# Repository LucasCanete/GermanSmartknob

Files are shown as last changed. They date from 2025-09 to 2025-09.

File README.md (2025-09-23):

# German Smartknob
An ESP32-S3 based knob to control smart devices at home. Based on Scott Bez's Smartknob: https://github.com/scottbez1/smartknob?tab=readme-ov-file. Adapted for the standard german wall socket.

## Table of Contents
1. [About the Project](#about-the-project)
2. [Features](#features)
3. [Components](#components)
4. [Getting Started](#getting-started)
5. [Project Status](#project-status)

## About the project
This project mechatronic project has three main parts. The first part consisted of the development of a PCB that could fit in the standard german wall socket and would control sensors, touch display and a BLDC Motor. The second part consisted on 3d printed pieces to sustain the PCB on its place, allow BLDC rotation while keeping the touch display on its place. Finally the third part was the software, which tested that all sensors and actuators worked accordingly. The final product can be seen below. 
<p align="center">
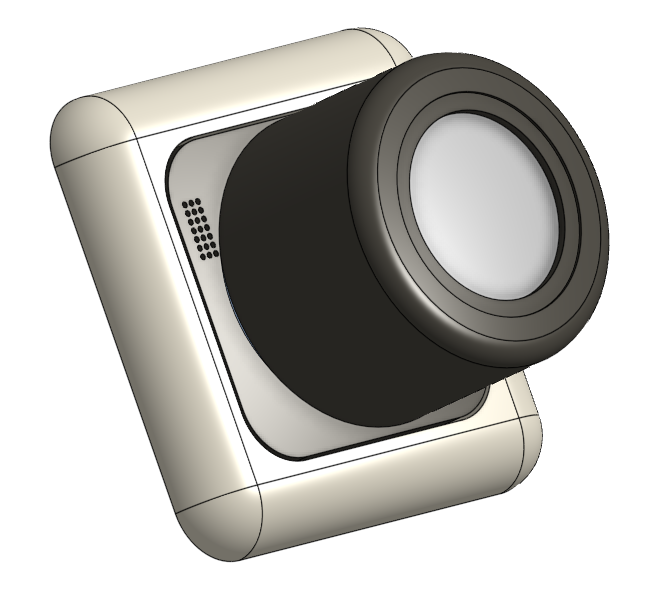
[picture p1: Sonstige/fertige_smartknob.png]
smartknob
   <br>
   <em>German Smartknob</em>
</p>

## Features
- ESP32-S3 based PCB
- Input Voltage of up to 24V
- Haptic Feedback with a BLDC-Motor (Coming soon)
- Touch Display
- Brightness and Temperature Sensor
- Audio speaker connectors

## Components
A summarized description of this products three main parts.
### PCB
The PCB was designed to fit into the standard german wall socket. It has two sides. 

On the front side there is a ring of RGB Leds for user feedback and at its center a magnetic encoder. The magnetic encoder is key to detect the rotation's direction of the BLDC Motor, that in this project is used as an input device, similar to a rotary encoder. The reason why a BLDC Motor was chosen and not a regular rotary encoder, is because with the first, through proper driver, it is possible to program the motor's torque and adjust it according to the user's use. Besides of this, at the sides of the Front-PCB there are sensors to detect the temperature, the room's brightness and also output audio via a speaker.

<p align="center">
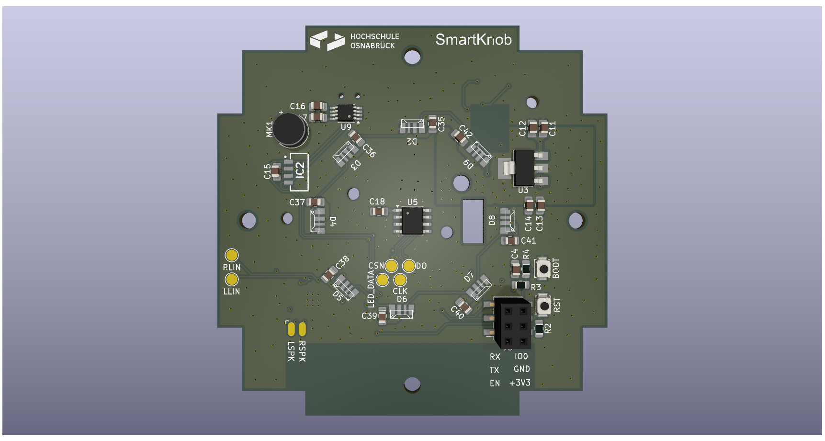
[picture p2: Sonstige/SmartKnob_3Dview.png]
Front side
   <br>
   <em>Figure 1: Front side PCB</em>
</p>

On the back side there are connectors available to supply the PCB with 24V, 3.3v and extra outputs with I2C and CAN lines. The Display connector pads, the ESP32-S3, and the audio and bldc driver are also found on the back side of the PCB.

<p align="center">
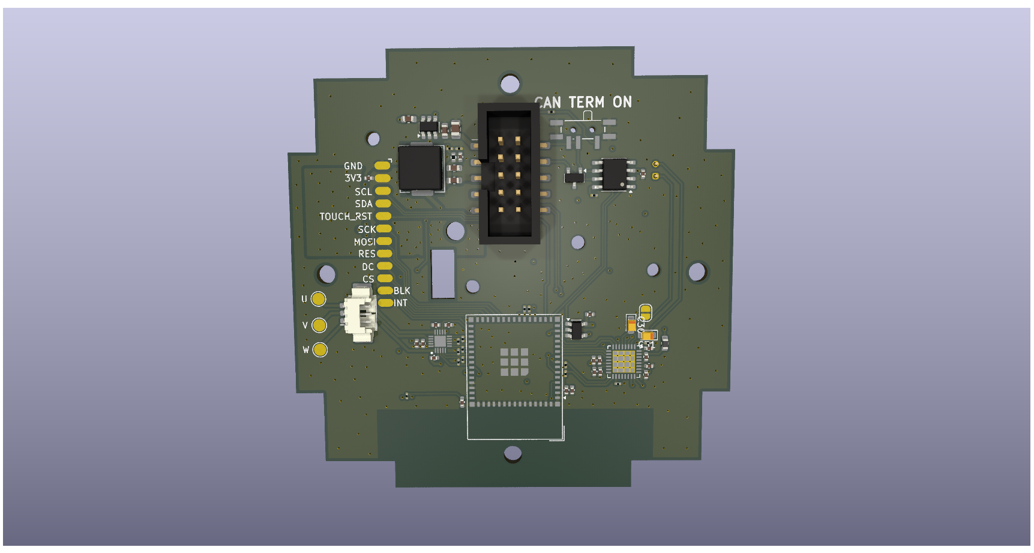
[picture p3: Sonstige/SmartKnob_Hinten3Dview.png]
Back side
   <br>
   <em>Figure 2: Backside PCB</em>
</p>

### 3D printed Parts
Using the OnShape CAD tool several 3D pieces were designed, that later were 3d printed. The pieces include a holder for the BLDC Motor to keep it in the middle; a holder for the display, a knob and a case to hide the electronic. Below is an exploded view of the internal pieces of the smartknob.

<p align="center">
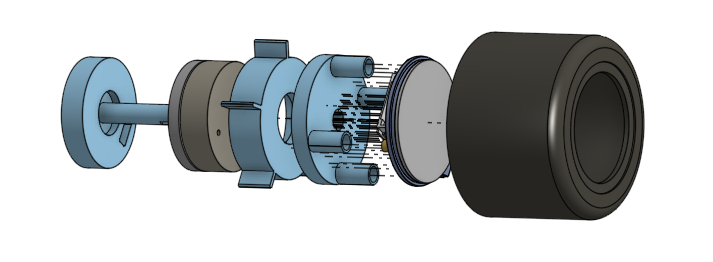
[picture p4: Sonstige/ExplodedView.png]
Exploded View
   <br>
   <em>Figure 3: Internal Pieces </em>
</p>

### Software
The software was built using the arduino libraries, for simplicities sake. The main goal of the software program was to demonstrate the correct functioning of the main features of the smartknob. Because of this, a small Manu was programmed in which 4 main features can be selected as options. With a tap on the touch display the option can be selected and the functioning of the feature can be demonstrated.

The four menu options and what each of them does is represented with the diagram below:

<p align="center">
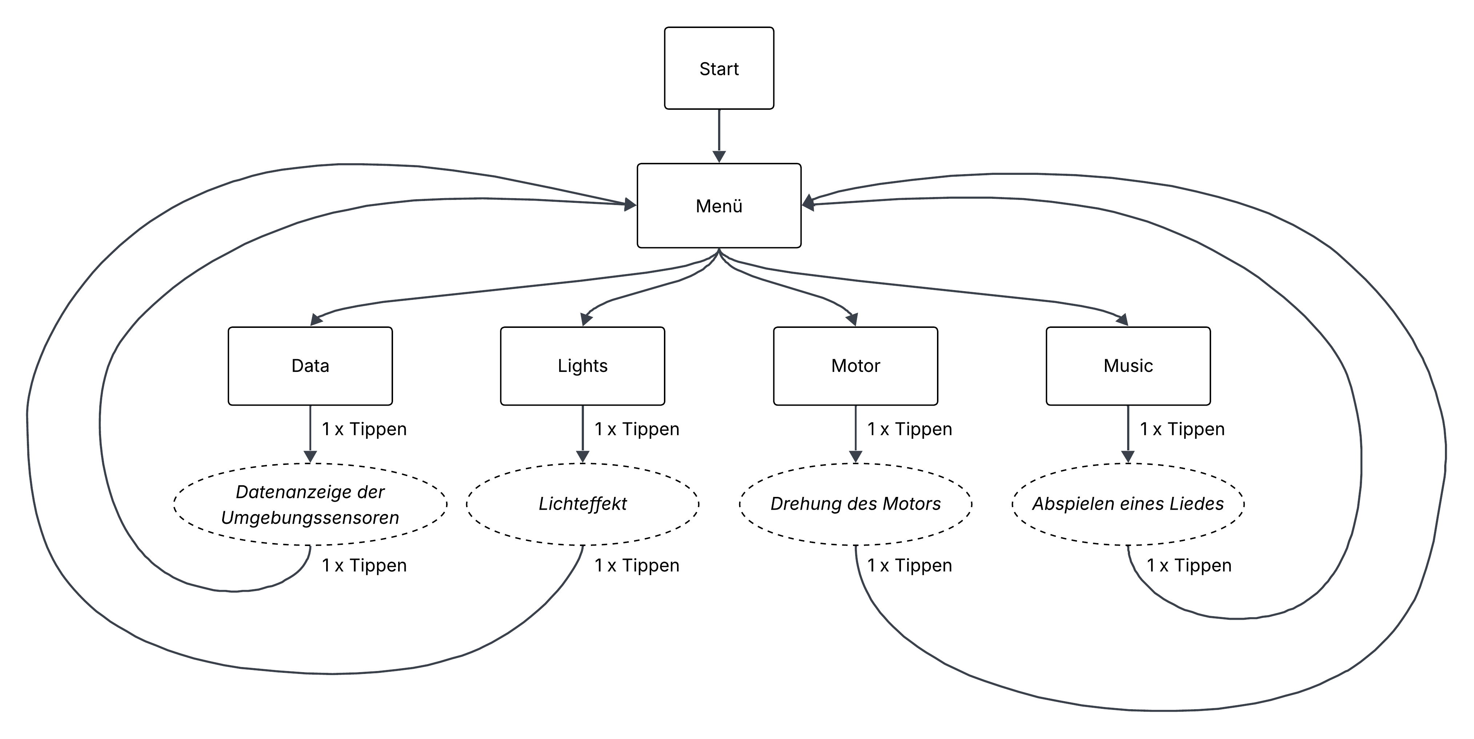
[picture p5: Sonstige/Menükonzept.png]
Software Diagram
   <br>
   <em>Figure 4: Software Diagram </em>
</p>

## Getting Started

### Download this repo
```
git clone https://github.com/LucasCanete/GermanSmartknob.git
```
### Build and upload 

### How To Use

<p align="center">
   Design 
 
   kitchenalarm
</p>

## Project Status
This project is still under development. Eventhough the first version was successful, improvements are still coming to the software side. Some of them are:
- [ ] Full implementation of haptic feedback
- [ ] Connection to smart devices over MQTT, home assistant, etc

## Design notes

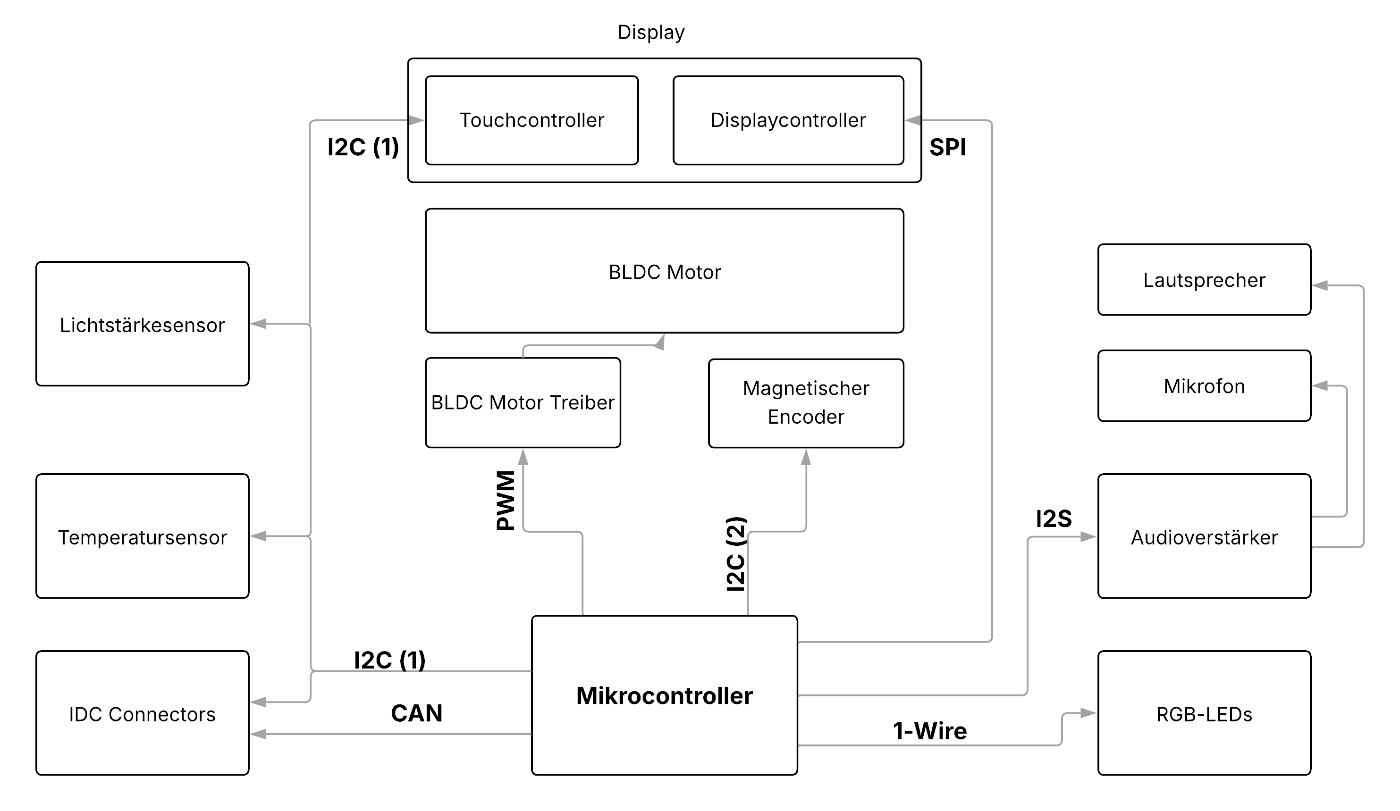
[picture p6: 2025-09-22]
Sonstige/HardwareArchitektur.png

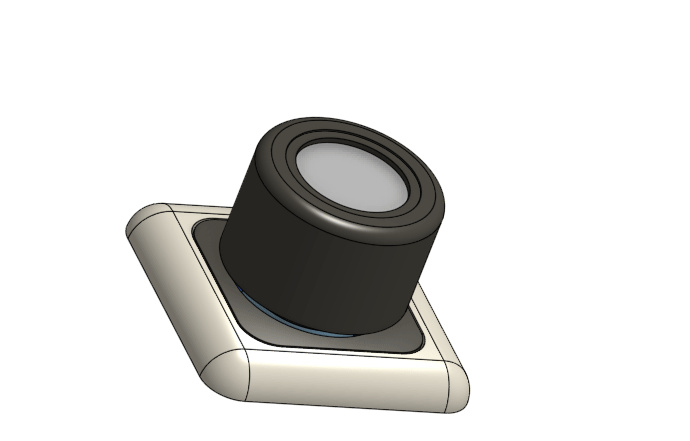
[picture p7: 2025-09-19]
Sonstige/drehung_1.gif

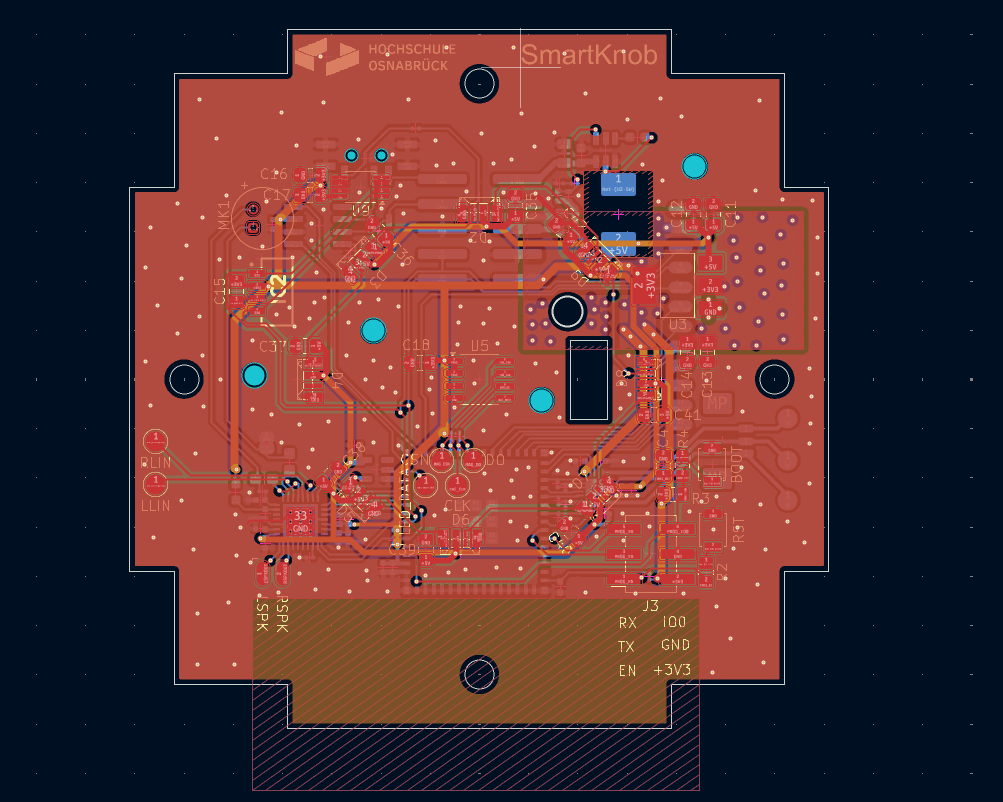
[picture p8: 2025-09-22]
Sonstige/2.ElektronischeArchitektur/Screenshot_Platine.png

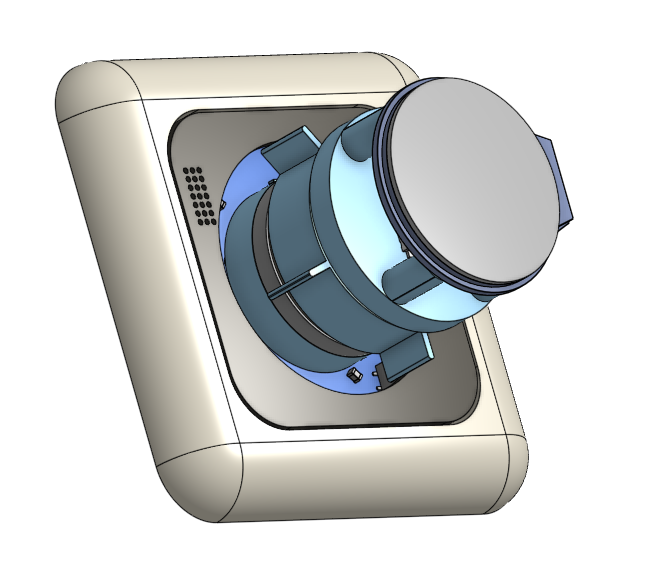
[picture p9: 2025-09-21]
Sonstige/Case.png

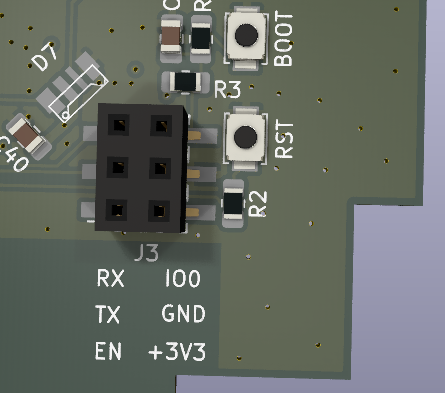
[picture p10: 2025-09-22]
Sonstige/2.ElektronischeArchitektur/screenshot_proganschluss.png

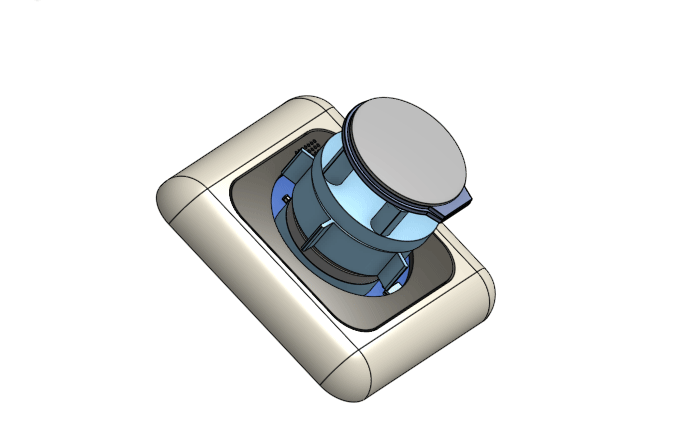
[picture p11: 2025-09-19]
Sonstige/drehung_2.gif

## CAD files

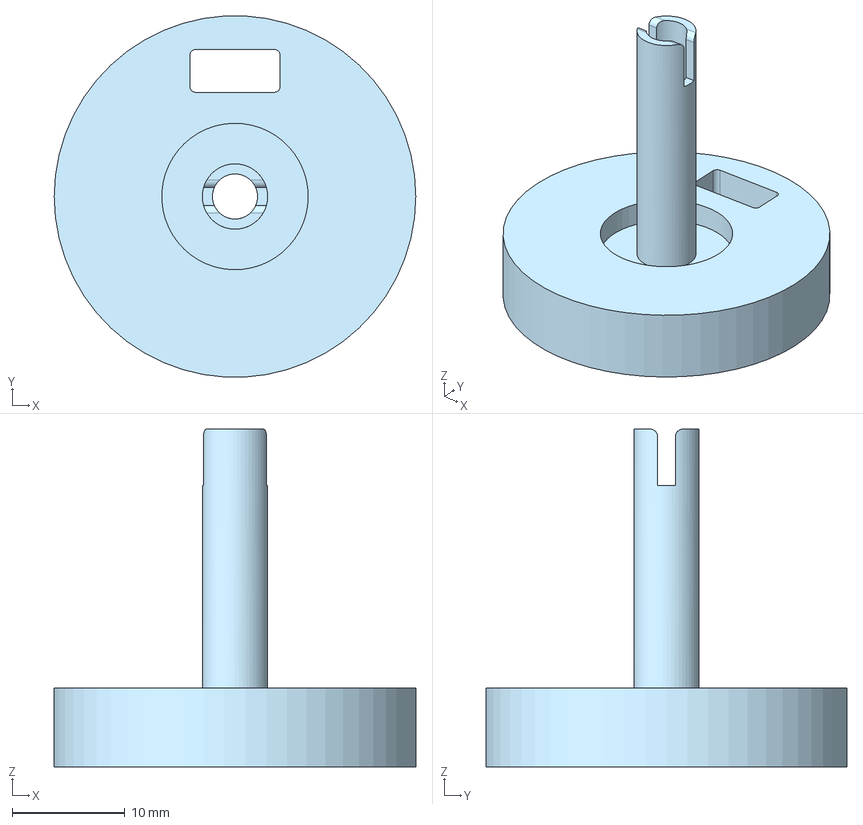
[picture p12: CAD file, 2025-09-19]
3DModelle/STEP/halterung.step
32.1 x 32.0 x 30.0 mm

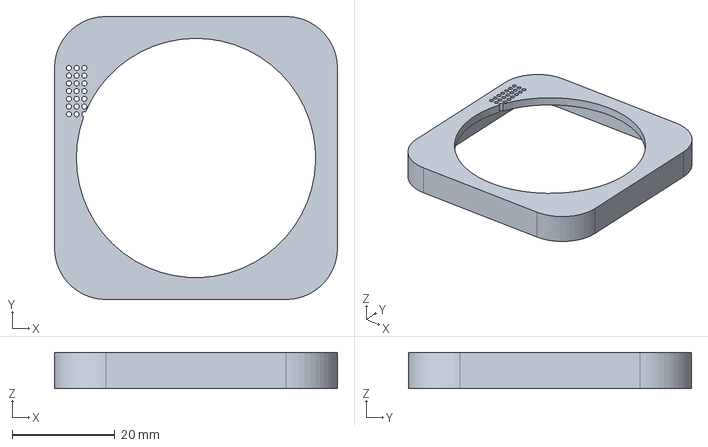
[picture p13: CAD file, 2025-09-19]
3DModelle/STEP/blende.step
55.0 x 55.0 x 7.00 mm

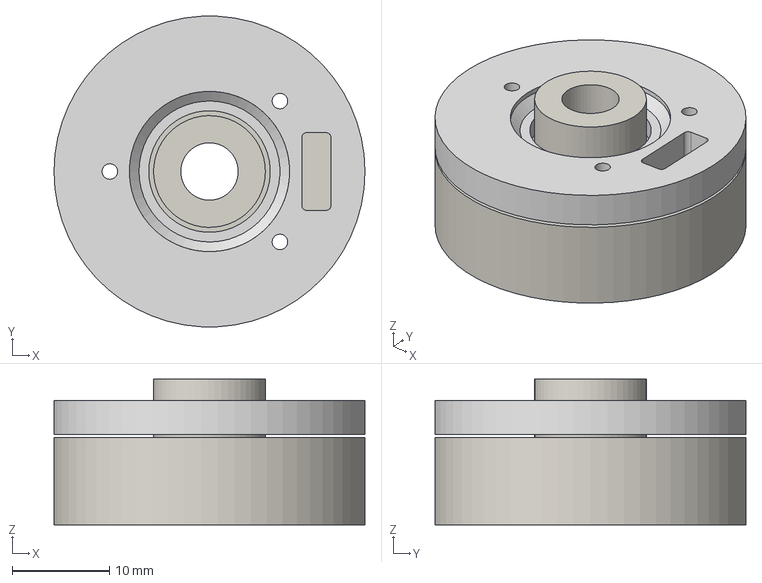
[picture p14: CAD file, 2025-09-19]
3DModelle/STEP/motor.step
32.0 x 32.0 x 15.0 mm

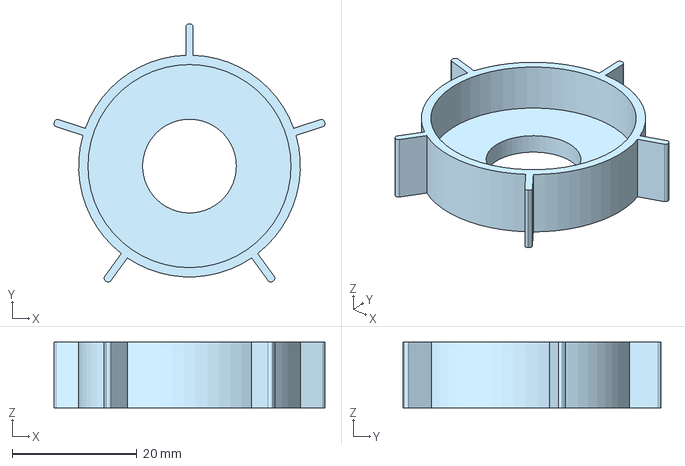
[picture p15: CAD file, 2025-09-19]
3DModelle/STEP/drehaufsatz.step
43.4 x 41.3 x 10.5 mm

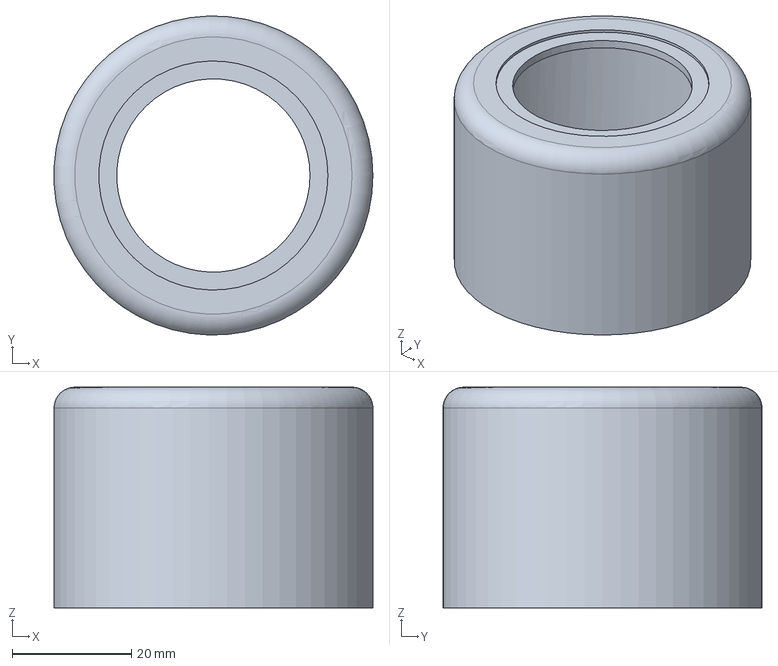
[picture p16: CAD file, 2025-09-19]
3DModelle/STEP/drehadapter.step
53.5 x 53.5 x 37.0 mm

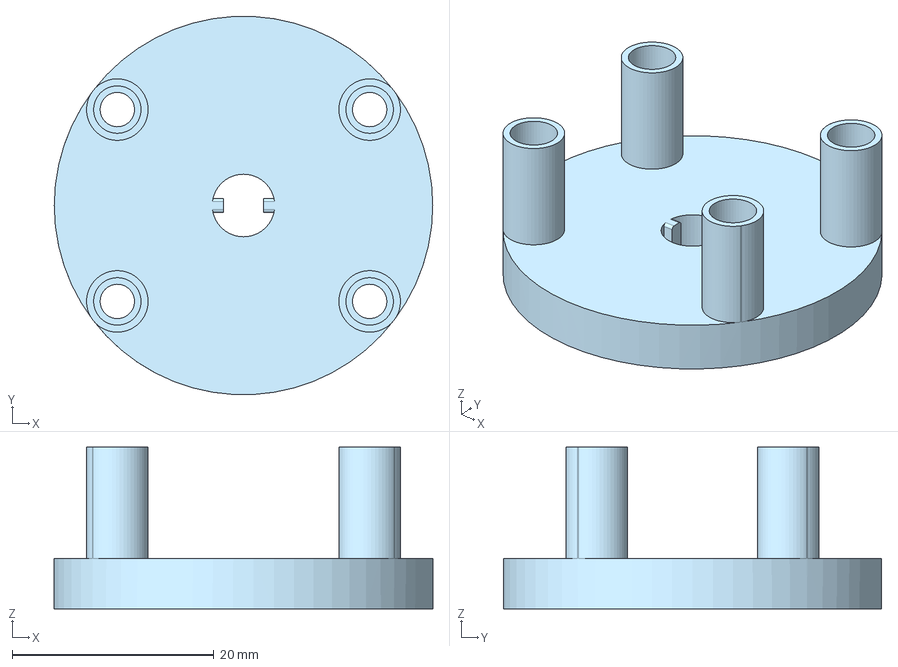
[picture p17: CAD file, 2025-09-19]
3DModelle/STEP/displayhalter.step
37.5 x 37.4 x 16.0 mm

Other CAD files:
3DModelle/STL/blende.stl
3DModelle/STL/displayhalter.stl
3DModelle/STL/drehadapter.stl
3DModelle/STL/drehaufsatz.stl
3DModelle/STL/halterung.stl

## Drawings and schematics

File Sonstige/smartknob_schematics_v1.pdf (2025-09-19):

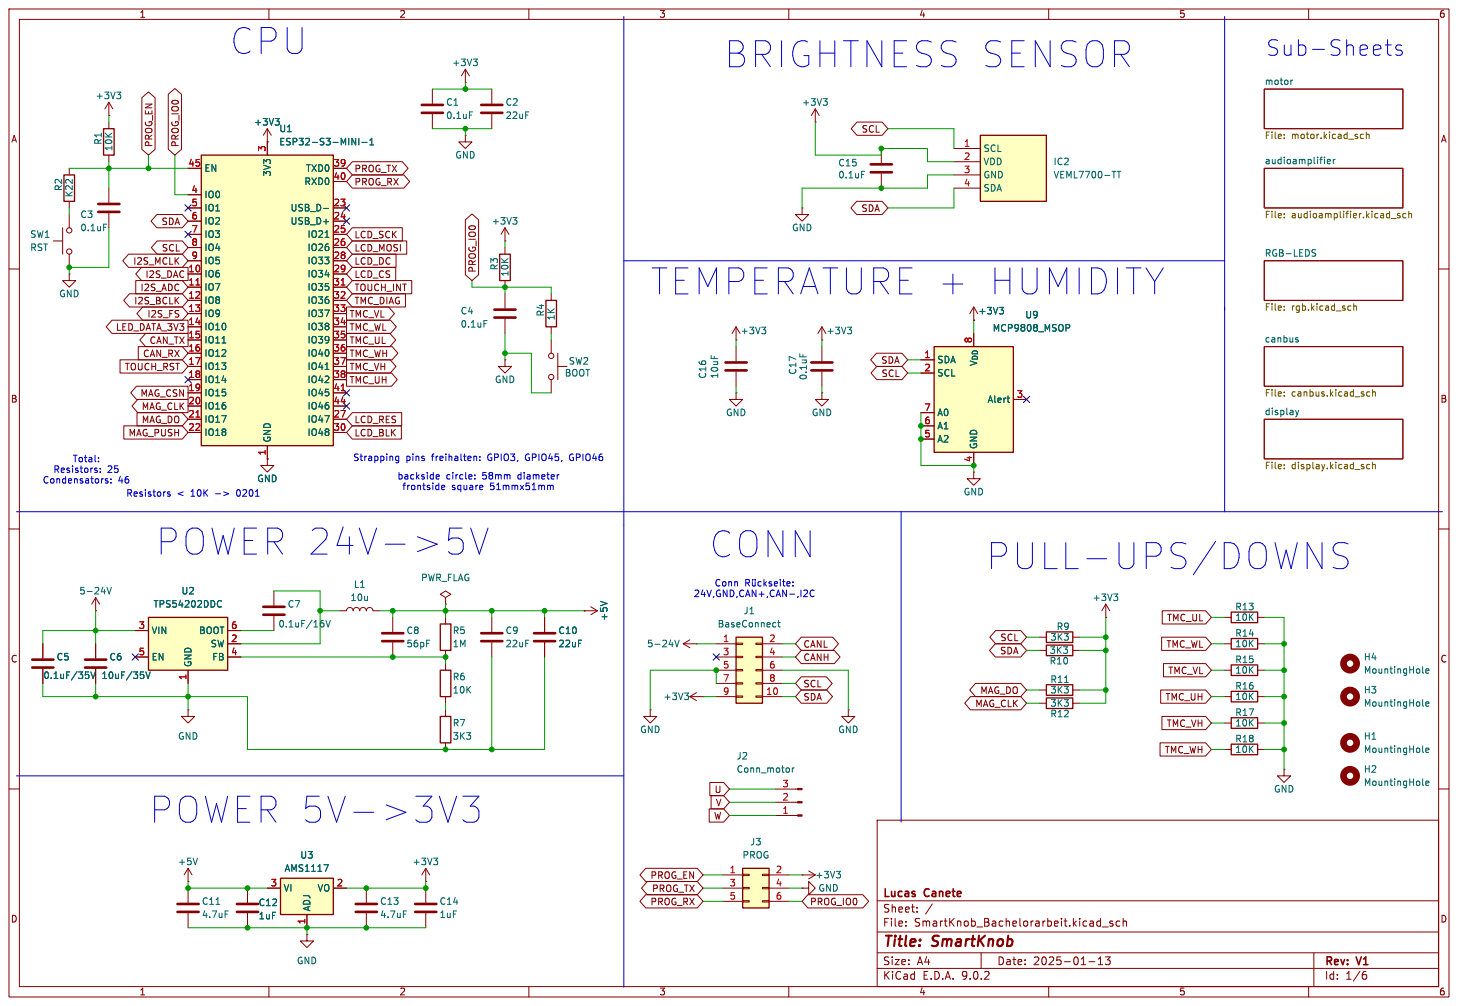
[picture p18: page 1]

File: rgb.kicad_sch motor File: motor.kicad_sch

canbus File: canbus.kicad_sch RGB-LEDS

CONN
PULL-UPS/DOWNS Conn þÿRückseite: 24V,GND,CAN+,CAN-,I2C

File: SmartKnob_Bachelorarbeit.kicad_sch Sheet: / Lucas Canete

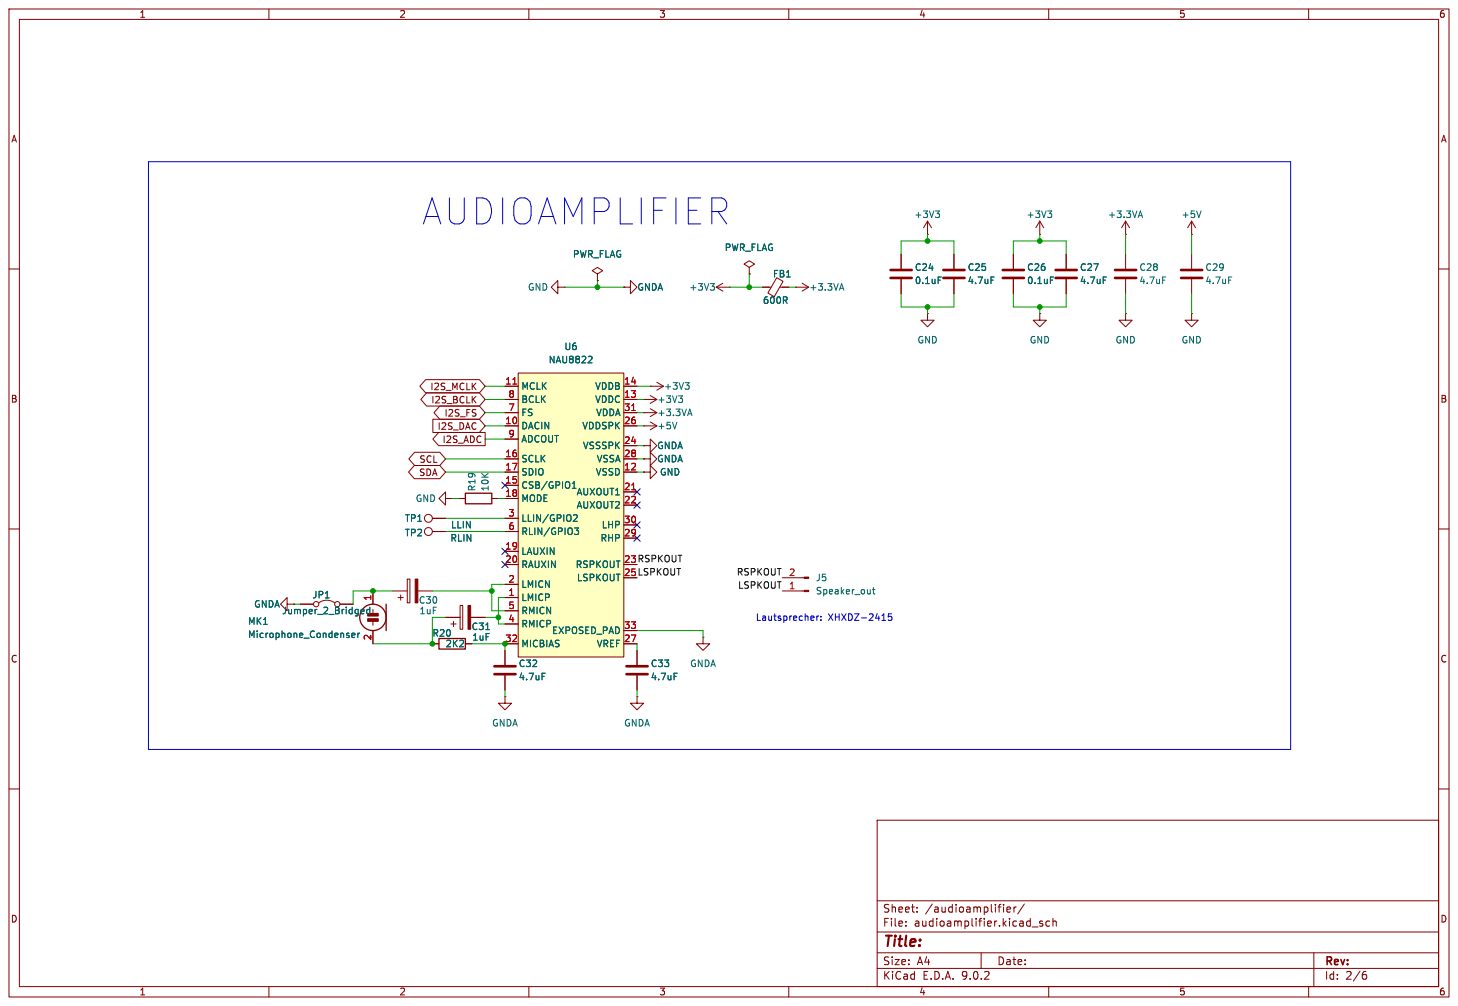
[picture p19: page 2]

Id: 2/6 Title: File: audioamplifier.kicad_sch Sheet: /audioamplifier/

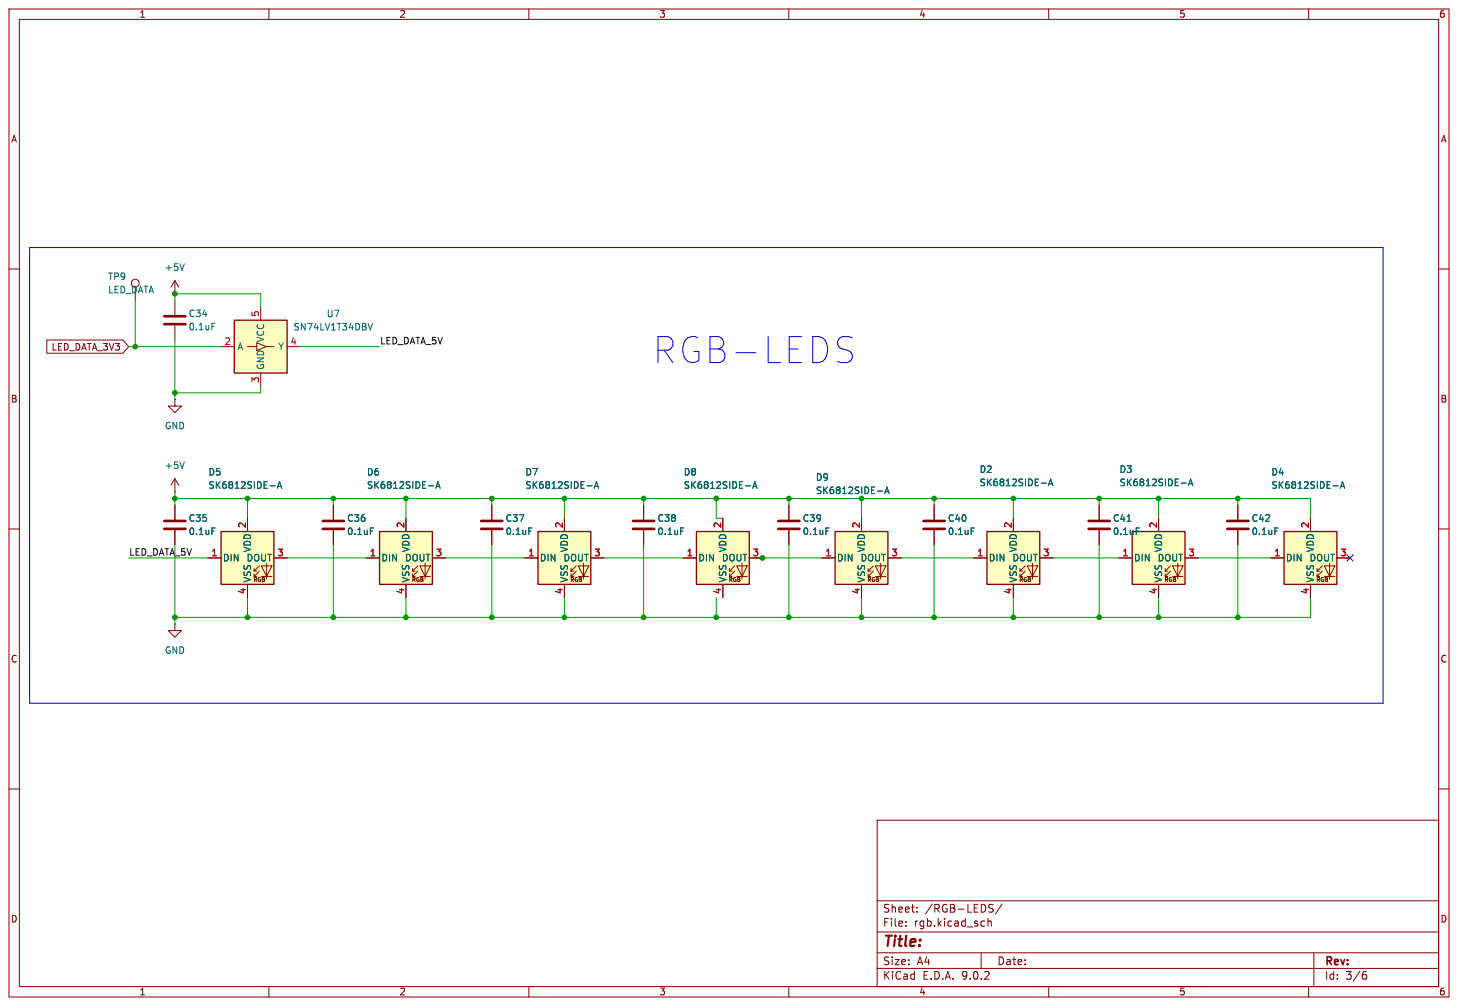
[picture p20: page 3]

Id: 3/6 Title: File: rgb.kicad_sch Sheet: /RGB-LEDS/ C38

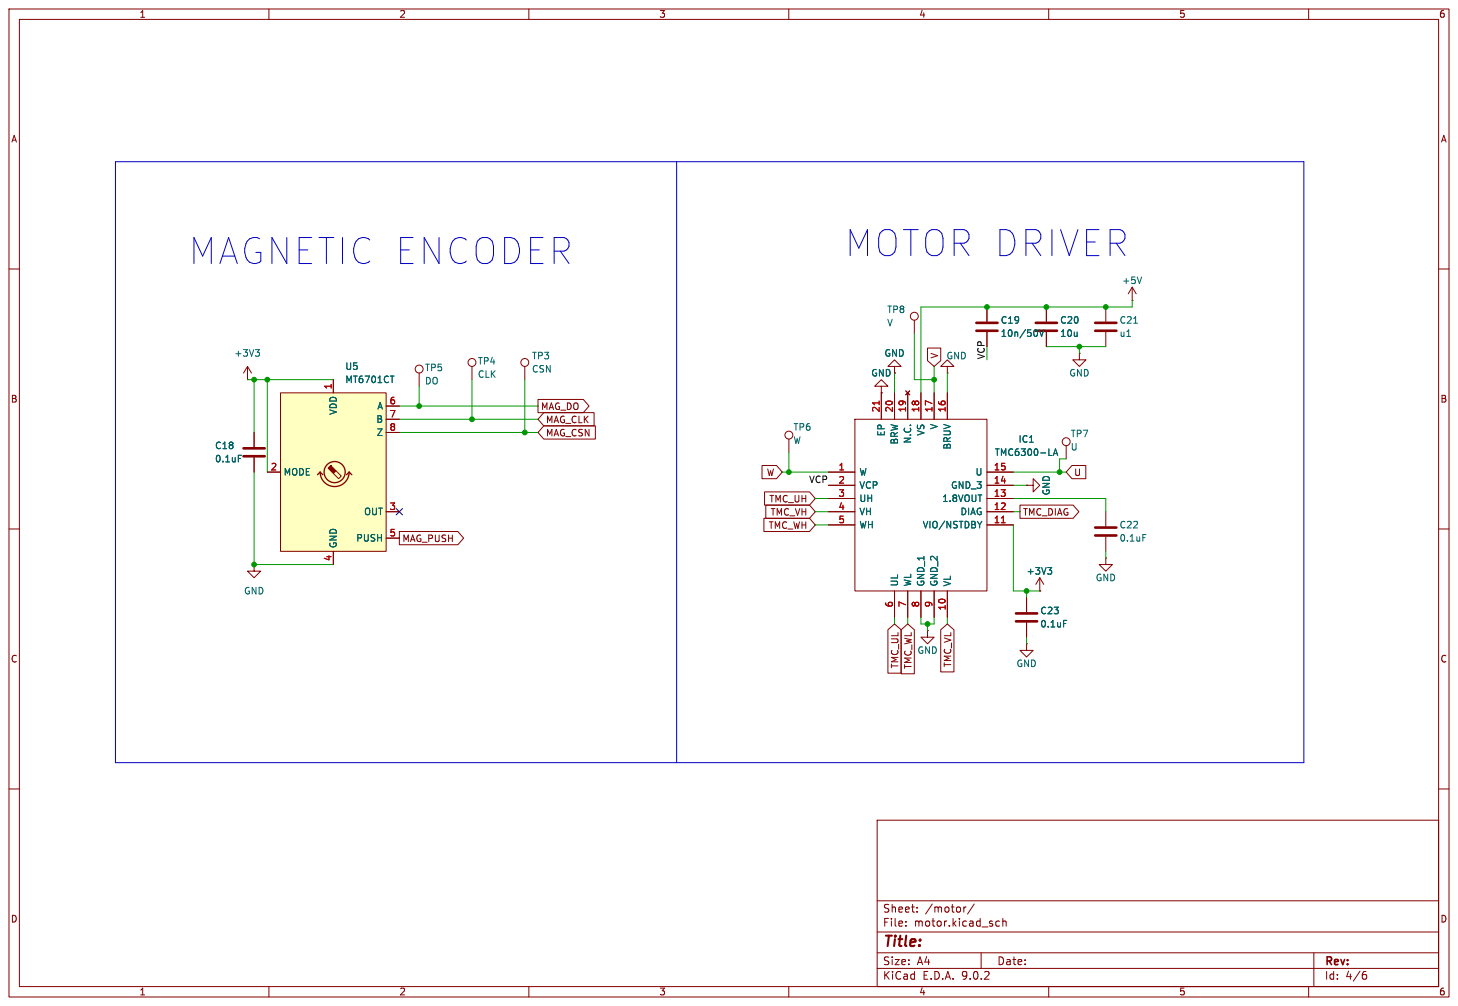
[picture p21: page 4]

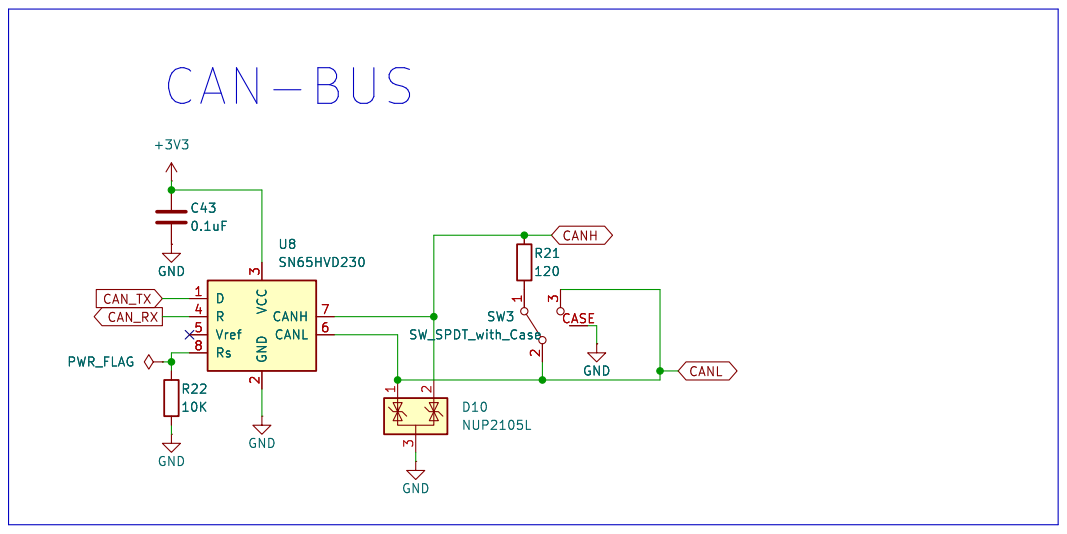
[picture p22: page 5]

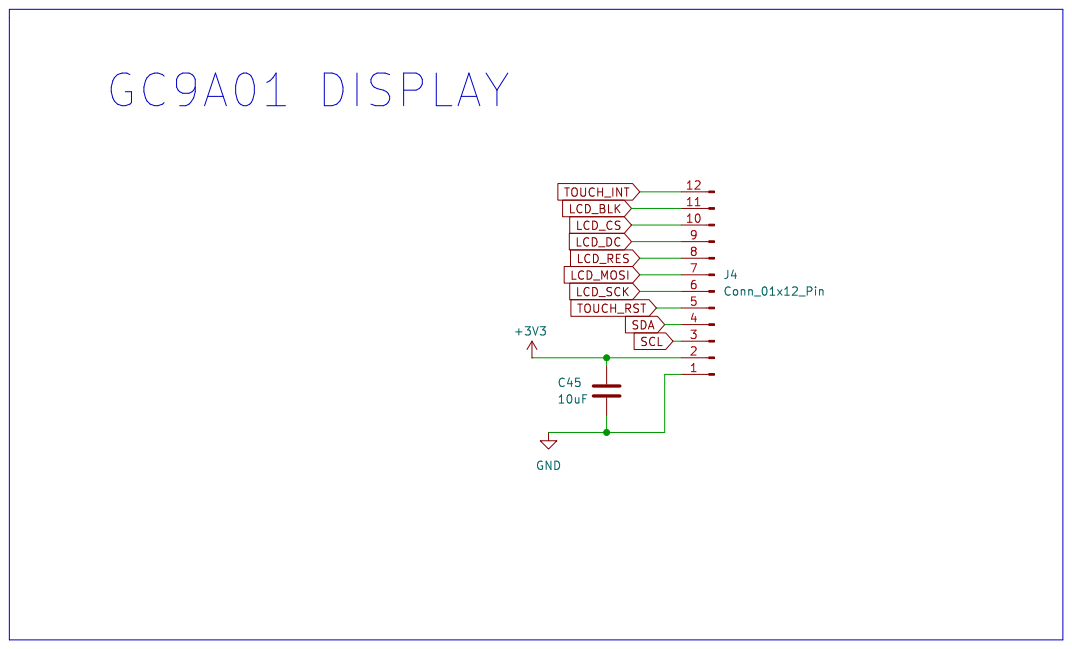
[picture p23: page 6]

Id: 6/6 Title: File: display.kicad_sch Sheet: /display/ GND

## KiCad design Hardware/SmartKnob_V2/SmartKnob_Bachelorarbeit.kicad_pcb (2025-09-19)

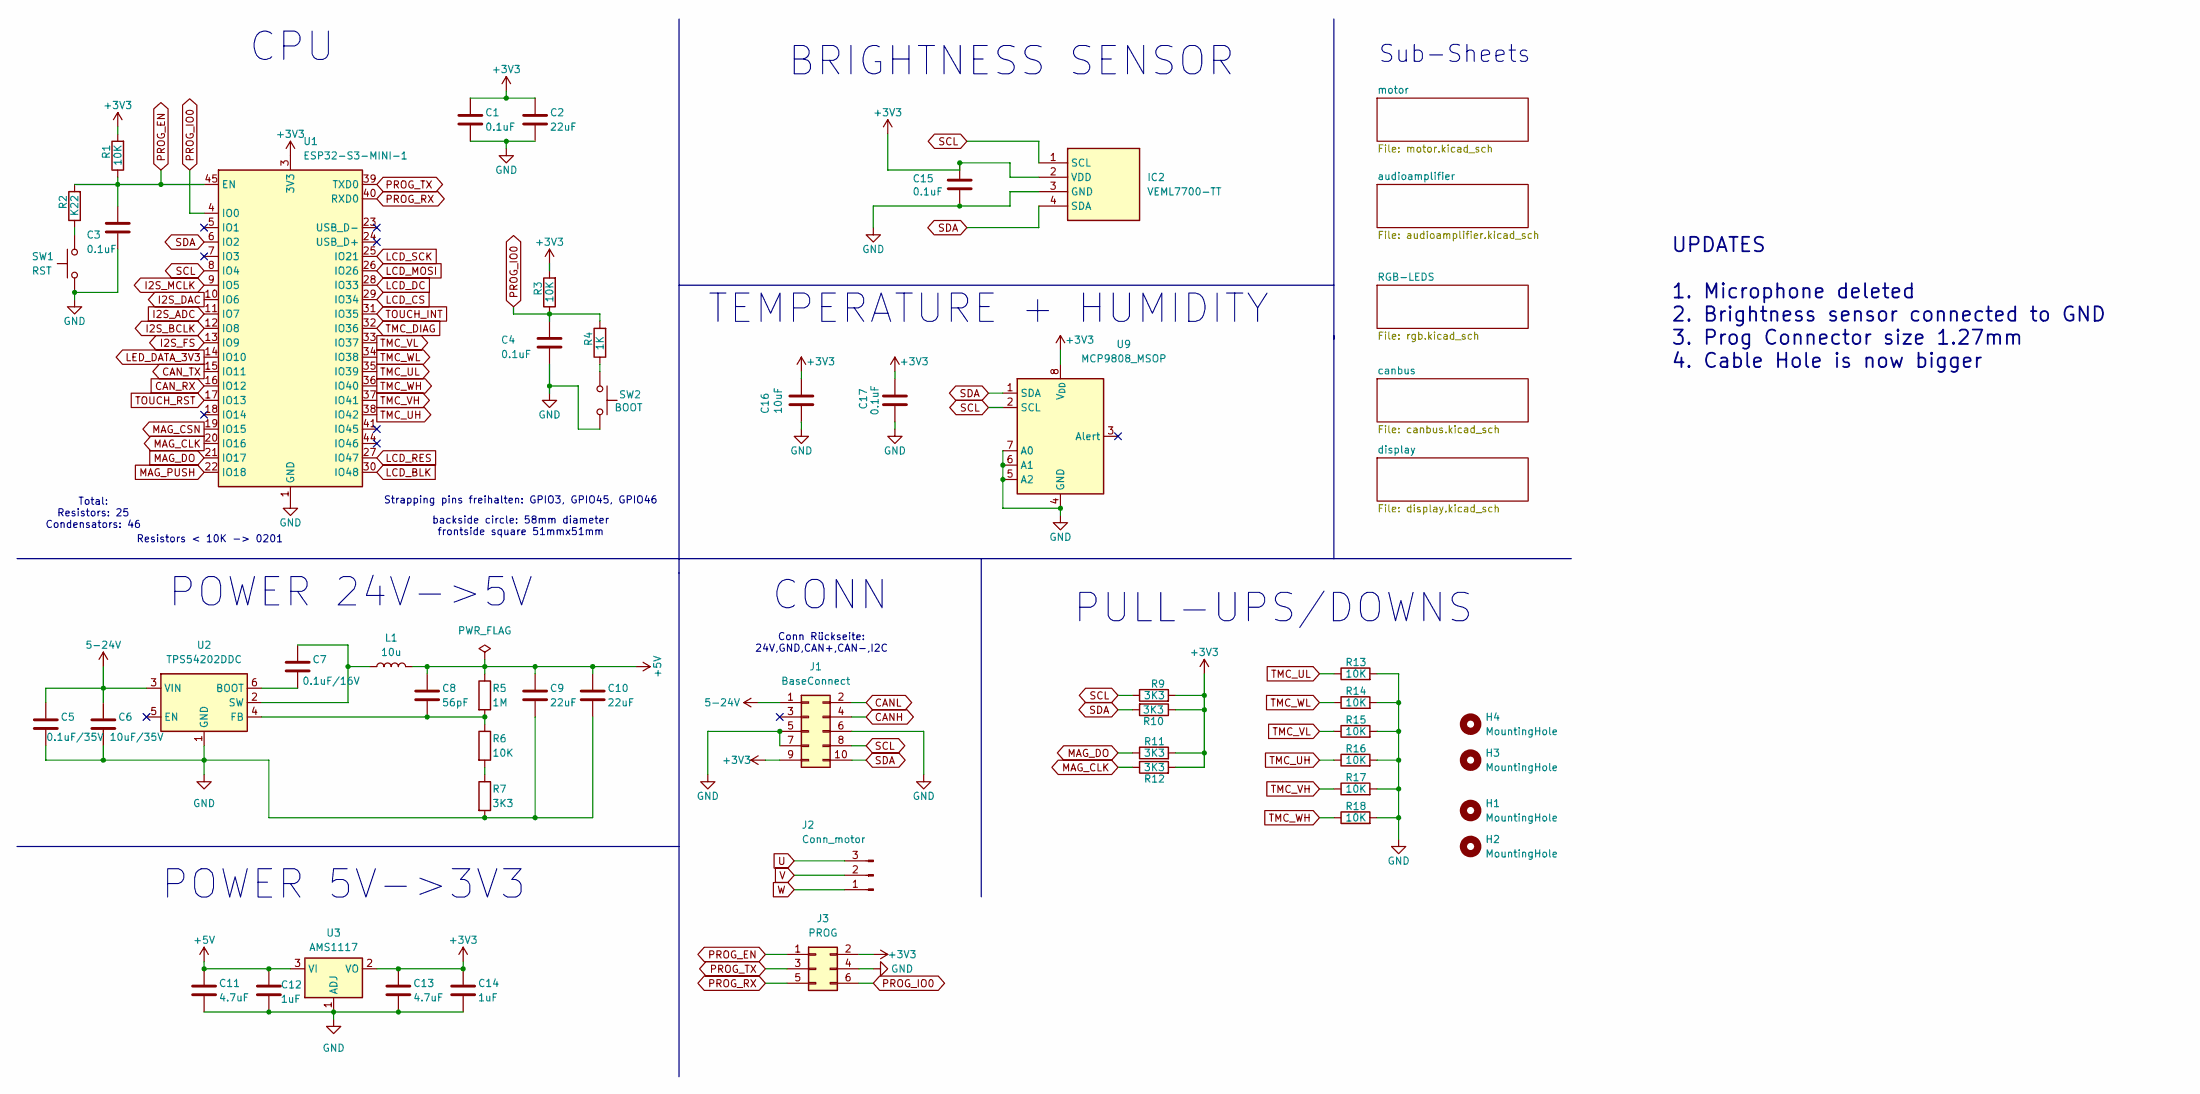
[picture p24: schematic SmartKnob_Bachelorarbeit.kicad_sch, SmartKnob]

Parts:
C1: 0.1uF; C_0402_1005Metric
C2: 22uF; C_0402_1005Metric
C3: 0.1uF; C_0402_1005Metric_Pad0.74x0.62mm_HandSolder
C4, C15, C17: 0.1uF; C_0805_2012Metric_Pad1.18x1.45mm_HandSolder
C5: 0.1uF/35V; C_0603_1608Metric
C6: 10uF/35V; C_0805_2012Metric
C7: 0.1uF/16V; C_0603_1608Metric
C8: 56pF; C_0402_1005Metric
C9, C10: 22uF; C_0603_1608Metric
C11, C13: 4.7uF; C_0805_2012Metric_Pad1.18x1.45mm_HandSolder
C12, C14: 1uF; C_0805_2012Metric_Pad1.18x1.45mm_HandSolder
C16: 10uF; C_0805_2012Metric_Pad1.18x1.45mm_HandSolder
H1, H2, H3: MountingHole; MountingHole_2.2mm_M2
H4: MountingHole; MountingHole_2.1mm
IC2: VEML7700-TT; VEML7700; Mouser Part Number 78-VEML7700-TT
J1: BaseConnect; IDC-Header_2x05_P2.54mm_Vertical_SMD
J2: Conn_motor; Molex_PicoBlade_53261-0371_1x03-1MP_P1.25mm_Horizontal
J3: PROG; PinHeader_2x03_P1.27mm_Vertical_SMD
L1: 10u; L_APV_APH0630
R1, R6, R13, R14, R15, R16, R17, R18: 10K; R_0201_0603Metric
R2: K22; R_0805_2012Metric_Pad1.20x1.40mm_HandSolder
R3: 10K; R_0805_2012Metric_Pad1.20x1.40mm_HandSolder
R4: 1K; R_0805_2012Metric_Pad1.20x1.40mm_HandSolder
R5: 1M; R_0402_1005Metric
R7, R9, R10, R11, R12: 3K3; R_0201_0603Metric
SW1: RST; SW_SPST_B3U-1000P
SW2: BOOT; SW_SPST_B3U-1000P
U1: ESP32-S3-MINI-1; ESP32-S2-MINI-1
U2: TPS54202DDC; SOT-23-6
U3: AMS1117; SOT-223-3_TabPin2_HANDSOLDER
U9: MCP9808_MSOP; MSOP-8_3x3mm_P0.65mm

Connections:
5-24V: C5.1, C6.1, J1.1, U2.3 (VIN)
+3V3: C1.1, C2.1, C13.1, C14.1, C15.2, C16.2, C17.2, IC2.2 (VDD), J1.9, J3.2, R1.2, R3.2, R9.2, R10.1, R11.2, R12.2, U1.3 (3V3), U3.2 (VO), U9.8 (V_{DD}); also elsewhere on the board
+5V: C8.1, C9.1, C10.1, C11.1, C12.1, L1.2, R5.1, U3.3 (VI); also elsewhere on the board
CANH: J1.4; also elsewhere on the board
CANL: J1.2; also elsewhere on the board
CAN_RX: U1.16 (IO12); also elsewhere on the board
CAN_TX: U1.15 (IO11); also elsewhere on the board
GND: C1.2, C2.2, C3.2, C4.2, C5.2, C6.2, C9.2, C10.2, C11.2, C12.2, C13.2, C14.2, C15.1, C16.1, C17.1, IC2.3 (GND), J1.5, J1.6, J1.7, J3.4, R7.2, R13.2, R14.2, R15.2, R16.2, R17.2, R18.2, SW1.1, SW2.2, U1.1 (GND), U1.2 (GND), U1.42 (GND), U1.43 (GND), U1.46 (GND), U1.47 (GND), U1.48 (GND), U1.49 (GND), U1.50 (GND), U1.51 (GND), U1.52 (GND), U1.53 (GND), U1.54 (GND), U1.55 (GND), U1.56 (GND), U1.57 (GND), U1.58 (GND), U1.59 (GND), U1.60 (GND), U1.61 (GND), U1.62 (GND), U1.63 (GND), U1.64 (GND), U1.65 (GND), U2.1 (GND), U3.1 (ADJ), U9.4 (GND), U9.5 (A2), U9.6 (A1), U9.7 (A0); also elsewhere on the board
I2S_ADC: U1.11 (IO7); also elsewhere on the board
I2S_BCLK: U1.12 (IO8); also elsewhere on the board
I2S_DAC: U1.10 (IO6); also elsewhere on the board
I2S_FS: U1.13 (IO9); also elsewhere on the board
I2S_MCLK: U1.9 (IO5); also elsewhere on the board
LCD_BLK: U1.30 (IO48); also elsewhere on the board
LCD_CS: U1.29 (IO34); also elsewhere on the board
LCD_DC: U1.28 (IO33); also elsewhere on the board
LCD_MOSI: U1.26 (IO26); also elsewhere on the board
LCD_RES: U1.27 (IO47); also elsewhere on the board
LCD_SCK: U1.25 (IO21); also elsewhere on the board
LED_DATA_3V3: U1.14 (IO10); also elsewhere on the board
MAG_CLK: R12.1, U1.20 (IO16); also elsewhere on the board
MAG_CSN: U1.19 (IO15); also elsewhere on the board
MAG_DO: R11.1, U1.21 (IO17); also elsewhere on the board
MAG_PUSH: U1.22 (IO18); also elsewhere on the board
unnamed: R2.1, SW1.2
unnamed: R4.1, SW2.1
unnamed: R6.2, R7.1
unnamed: C7.2, U2.6 (BOOT)
unnamed: C8.2, R5.2, R6.1, U2.4 (FB)
unnamed: C7.1, L1.1, U2.2 (SW)
PROG_EN: C3.1, J3.1, R1.1, R2.2, U1.45 (EN)
PROG_IO0: C4.1, J3.6, R3.1, R4.2, U1.4 (IO0)
PROG_RX: J3.5, U1.40 (RXD0)
PROG_TX: J3.3, U1.39 (TXD0)
SCL: IC2.1 (SCL), J1.8, R9.1, U1.8 (IO4), U9.2 (SCL); also elsewhere on the board
SDA: IC2.4 (SDA), J1.10, R10.2, U1.6 (IO2), U9.1 (SDA); also elsewhere on the board
TMC_DIAG: U1.32 (IO36); also elsewhere on the board
TMC_UH: R16.1, U1.38 (IO42); also elsewhere on the board
TMC_UL: R13.1, U1.35 (IO39); also elsewhere on the board
TMC_VH: R17.1, U1.37 (IO41); also elsewhere on the board
TMC_VL: R15.1, U1.33 (IO37); also elsewhere on the board
TMC_WH: R18.1, U1.36 (IO40); also elsewhere on the board
TMC_WL: R14.1, U1.34 (IO38); also elsewhere on the board
TOUCH_INT: U1.31 (IO35); also elsewhere on the board
TOUCH_RST: U1.17 (IO13); also elsewhere on the board
U: J2.3; also elsewhere on the board
V: J2.2; also elsewhere on the board
W: J2.1; also elsewhere on the board

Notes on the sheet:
Sub-Sheets
TEMPERATURE + HUMIDITY
Total: Resistors: 25 Condensators: 46
POWER 5V->3V3
CONN
CPU
Conn Rückseite: 24V,GND,CAN+,CAN-,I2C
BRIGHTNESS SENSOR
Resistors < 10K -> 0201
Strapping pins freihalten: GPIO3, GPIO45, GPIO46
backside circle: 58mm diameter frontside square 51mmx51mm
UPDATES 1. Microphone deleted 2. Brightness sensor connected to GND 3. Prog Connector size 1.27mm 4. Cable Hole is now bigger
POWER 24V->5V
PULL-UPS/DOWNS

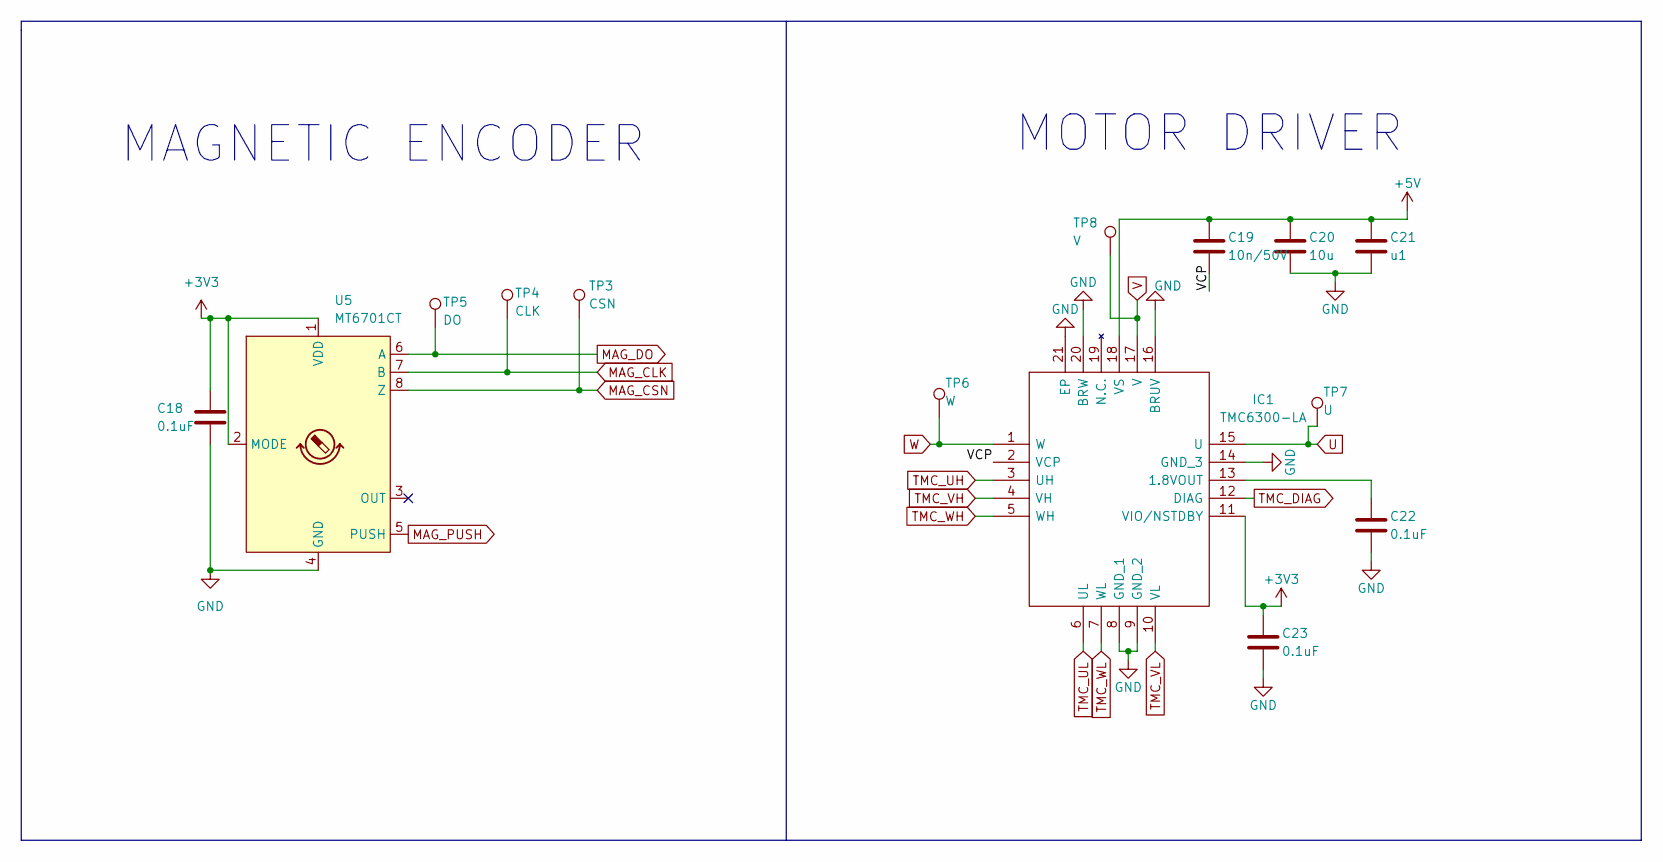
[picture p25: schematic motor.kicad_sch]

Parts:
C18: 0.1uF; C_0805_2012Metric_Pad1.18x1.45mm_HandSolder
C19: 10n/50V; C_0402_1005Metric
C20: 10u; C_0402_1005Metric
C21: u1; C_0402_1005Metric
C22, C23: 0.1uF; C_0402_1005Metric
IC1: TMC6300-LA; QFN40P300X300X90-21N; Mouser Part Number 700-TMC6300-LA
TP3: CSN; TestPoint_Pad_D2.0mm
TP4: CLK; TestPoint_Pad_D2.0mm
TP5: DO; TestPoint_Pad_D2.0mm
TP6: W; TestPoint_Pad_D2.0mm
TP7: U; TestPoint_Pad_D2.0mm
TP8: V; TestPoint_Pad_D2.0mm
U5: MT6701CT; SO-8_3.9x4.9mm_P1.27mm

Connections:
+3V3: C18.1, C23.1, IC1.11 (VIO/NSTDBY), U5.1 (VDD), U5.2 (MODE); also elsewhere on the board
+5V: C19.1, C20.1, C21.1, IC1.18 (VS); also elsewhere on the board
/motor/VCP: C19.2, IC1.2 (VCP)
GND: C18.2, C20.2, C21.2, C22.2, C23.2, IC1.8 (GND_1), IC1.9 (GND_2), IC1.14 (GND_3), IC1.16 (BRUV), IC1.20 (BRW), IC1.21 (EP), U5.4 (GND); also elsewhere on the board
MAG_CLK: TP4.1, U5.7 (B); also elsewhere on the board
MAG_CSN: TP3.1, U5.8 (Z); also elsewhere on the board
MAG_DO: TP5.1, U5.6 (A); also elsewhere on the board
MAG_PUSH: U5.5 (PUSH); also elsewhere on the board
unnamed: C22.1, IC1.13 (1.8VOUT)
TMC_DIAG: IC1.12 (DIAG); also elsewhere on the board
TMC_UH: IC1.3 (UH); also elsewhere on the board
TMC_UL: IC1.6 (UL); also elsewhere on the board
TMC_VH: IC1.4 (VH); also elsewhere on the board
TMC_VL: IC1.10 (VL); also elsewhere on the board
TMC_WH: IC1.5 (WH); also elsewhere on the board
TMC_WL: IC1.7 (WL); also elsewhere on the board
U: IC1.15 (U), TP7.1; also elsewhere on the board
V: IC1.17 (V), TP8.1; also elsewhere on the board
W: IC1.1 (W), TP6.1; also elsewhere on the board

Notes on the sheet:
MOTOR DRIVER
MAGNETIC ENCODER

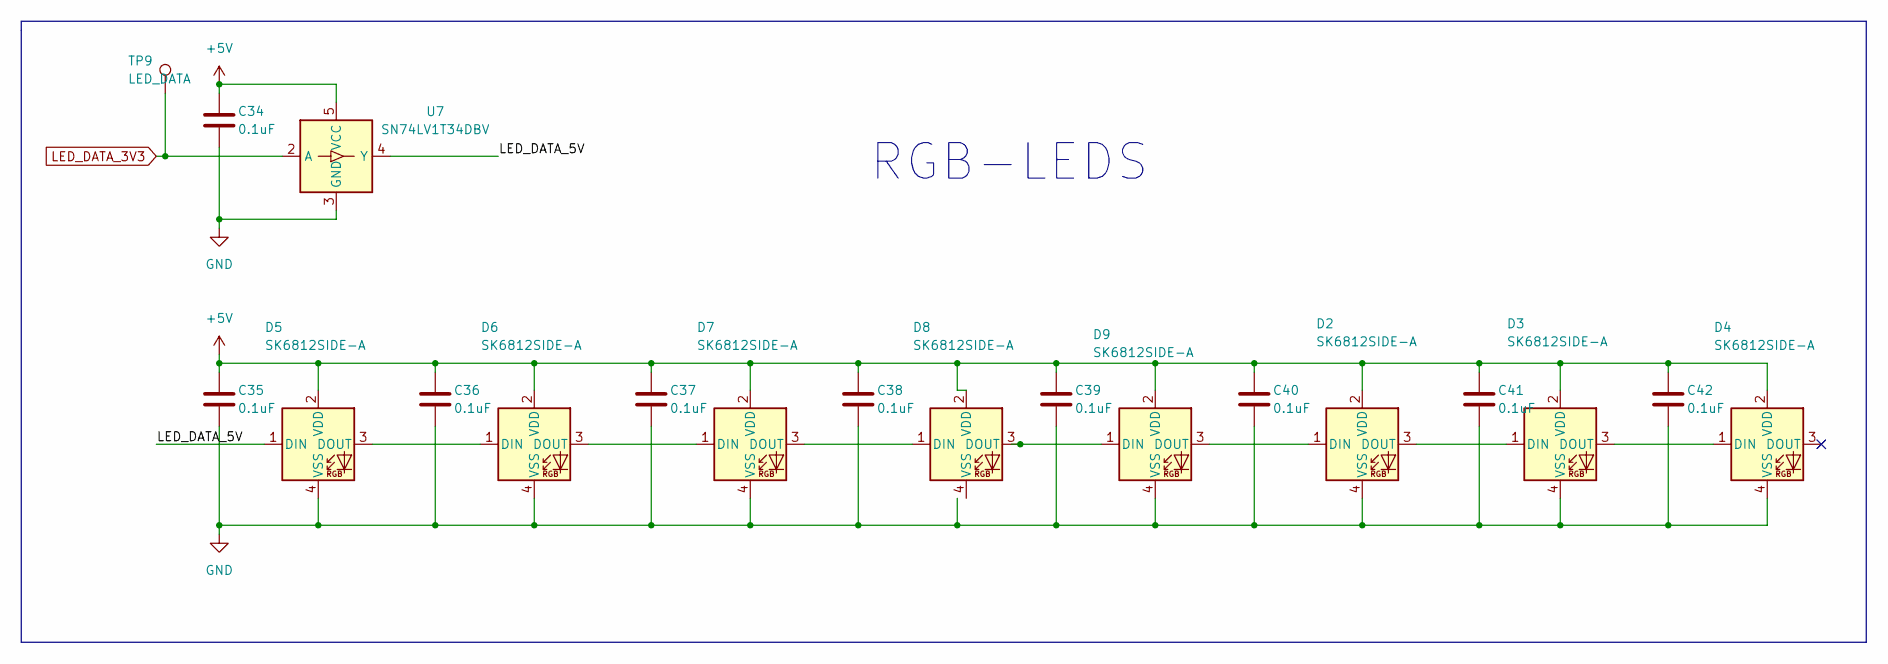
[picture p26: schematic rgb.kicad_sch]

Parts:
C34: 0.1uF; C_0402_1005Metric
C35, C36, C37, C38, C39, C40, C41, C42: 0.1uF; C_0805_2012Metric_Pad1.18x1.45mm_HandSolder
D2, D3, D4, D5, D6, D7, D8, D9: SK6812SIDE-A; SK6812_SIDE_A_handsolder; Digikey 1528-4691-ND
TP9: LED_DATA; TestPoint_Pad_D2.0mm
U7: SN74LV1T34DBV; SOT-23-5

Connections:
+5V: C34.1, C35.1, C36.1, C37.1, C38.1, C39.1, C40.1, C41.1, C42.1, D2.2 (VDD), D3.2 (VDD), D4.2 (VDD), D5.2 (VDD), D6.2 (VDD), D7.2 (VDD), D8.2 (VDD), D9.2 (VDD), U7.5 (VCC); also elsewhere on the board
/RGB-LEDS/LED_DATA_5V: D5.1 (DIN), U7.4 (Y)
GND: C34.2, C35.2, C36.2, C37.2, C38.2, C39.2, C40.2, C41.2, C42.2, D2.4 (VSS), D3.4 (VSS), D4.4 (VSS), D5.4 (VSS), D6.4 (VSS), D7.4 (VSS), D9.4 (VSS), U7.3 (GND); also elsewhere on the board
LED_DATA_3V3: TP9.1, U7.2 (A); also elsewhere on the board
unnamed: D2.1 (DIN), D9.3 (DOUT)
unnamed: D2.3 (DOUT), D3.1 (DIN)
unnamed: D3.3 (DOUT), D4.1 (DIN)
unnamed: D5.3 (DOUT), D6.1 (DIN)
unnamed: D6.3 (DOUT), D7.1 (DIN)
unnamed: D7.3 (DOUT), D8.1 (DIN)
unnamed: D8.3 (DOUT), D9.1 (DIN)

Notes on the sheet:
RGB-LEDS

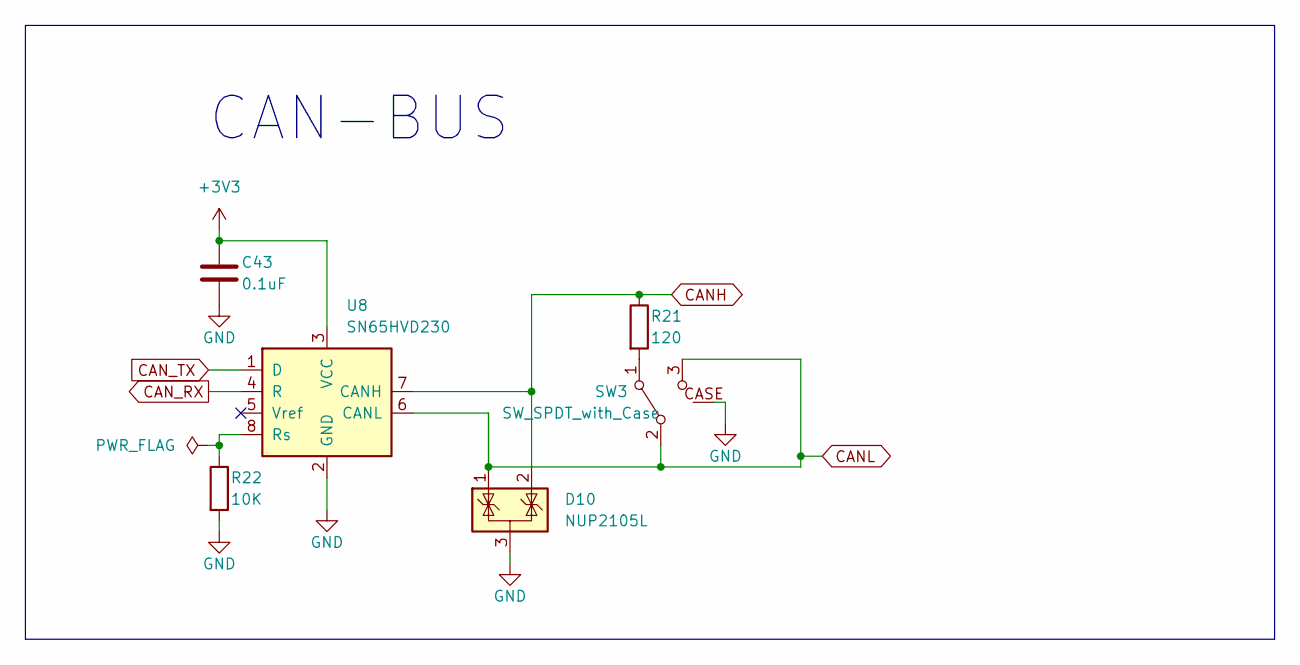
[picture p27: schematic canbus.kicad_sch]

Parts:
C43: 0.1uF; C_0402_1005Metric
D10: NUP2105L; SOT-23
R21: 120; R_0201_0603Metric
R22: 10K; R_0201_0603Metric
SW3: SW_SPDT_with_Case; SW_SPDT_PCM12_handsolder
U8: SN65HVD230; SOIC-8_3.9x4.9mm_P1.27mm

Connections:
+3V3: C43.1, U8.3 (VCC); also elsewhere on the board
CANH: D10.2 (K), R21.1, U8.7 (CANH); also elsewhere on the board
CANL: D10.1 (K), SW3.2 (B), SW3.3 (C), U8.6 (CANL); also elsewhere on the board
CAN_RX: U8.4 (R); also elsewhere on the board
CAN_TX: U8.1 (D); also elsewhere on the board
GND: C43.2, D10.3 (A), R22.2, SW3.CASE, U8.2 (GND); also elsewhere on the board
unnamed: R21.2, SW3.1 (A)
unnamed: R22.1, U8.8 (Rs)

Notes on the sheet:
CAN-BUS

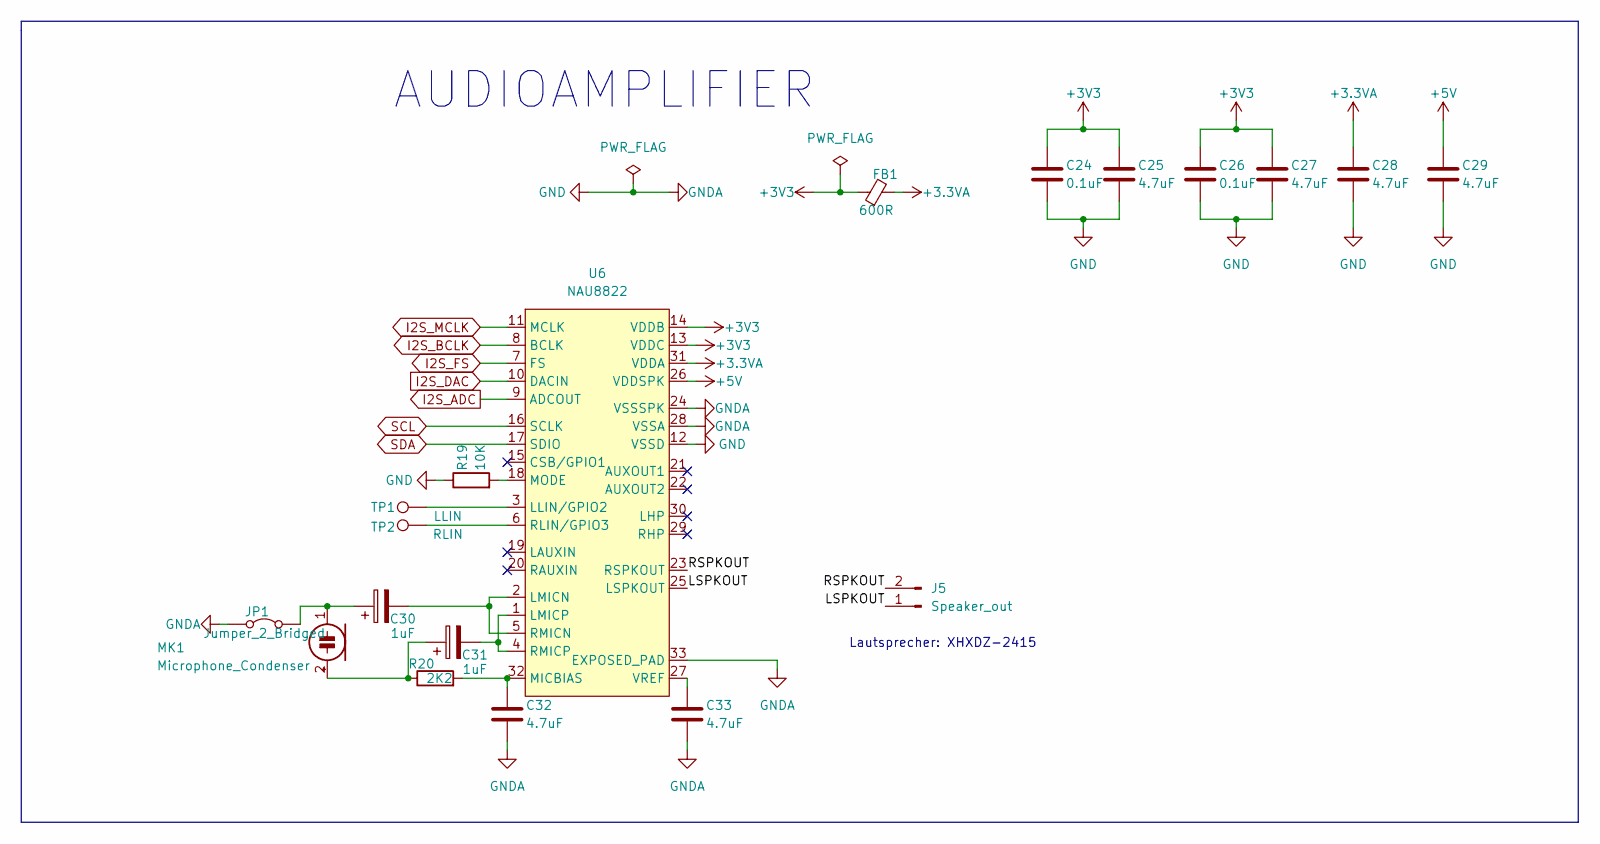
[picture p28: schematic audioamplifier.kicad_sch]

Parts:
C24, C26: 0.1uF; C_0402_1005Metric
C25, C27, C28, C29, C32, C33: 4.7uF; C_0402_1005Metric
C30, C31: 1uF; CP_EIA-2012-12_Kemet-R
FB1: 600R; L_0603_1608Metric
J5: Speaker_out; SolderPads_2mm_2
JP1: Jumper_2_Bridged; SolderJumper-2_P1.3mm_Bridged2Bar_RoundedPad1.0x1.5mm
MK1: Microphone_Condenser; POM-2244P-C3310-2-R
R19: 10K; R_0201_0603Metric
R20: 2K2; R_0201_0603Metric
TP1: LLIN; TestPoint_Pad_D2.0mm
TP2: RLIN; TestPoint_Pad_D2.0mm
U6: NAU8822; QFN-32-1EP_5x5mm_P0.5mm_EP3.6x3.6mm_ThermalVias

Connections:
+3.3VA: C28.1, FB1.2, U6.31 (VDDA)
+3V3: C24.1, C25.1, C26.1, C27.1, FB1.1, U6.13 (VDDC), U6.14 (VDDB); also elsewhere on the board
+5V: C29.1, U6.26 (VDDSPK); also elsewhere on the board
/audioamplifier/LSPKOUT: J5.1, U6.25 (LSPKOUT)
/audioamplifier/RSPKOUT: J5.2, U6.23 (RSPKOUT)
GND: C24.2, C25.2, C26.2, C27.2, C28.2, C29.2, C32.2, C33.2, JP1.1 (A), R19.1, U6.12 (VSSD), U6.24 (VSSSPK), U6.28 (VSSA), U6.33 (EXPOSED_PAD); also elsewhere on the board
I2S_ADC: U6.9 (ADCOUT); also elsewhere on the board
I2S_BCLK: U6.8 (BCLK); also elsewhere on the board
I2S_DAC: U6.10 (DACIN); also elsewhere on the board
I2S_FS: U6.7 (FS); also elsewhere on the board
I2S_MCLK: U6.11 (MCLK); also elsewhere on the board
unnamed: C30.1, JP1.2 (B), MK1.1 (-)
unnamed: C31.1, MK1.2 (+), R20.1
unnamed: TP1.1, U6.3 (LLIN/GPIO2)
unnamed: C30.2, U6.2 (LMICN), U6.5 (RMICN)
unnamed: C31.2, U6.1 (LMICP), U6.4 (RMICP)
unnamed: C32.1, R20.2, U6.32 (MICBIAS)
unnamed: R19.2, U6.18 (MODE)
unnamed: TP2.1, U6.6 (RLIN/GPIO3)
unnamed: C33.1, U6.27 (VREF)
SCL: U6.16 (SCLK); also elsewhere on the board
SDA: U6.17 (SDIO); also elsewhere on the board

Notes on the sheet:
Lautsprecher: XHXDZ-2415
AUDIOAMPLIFIER

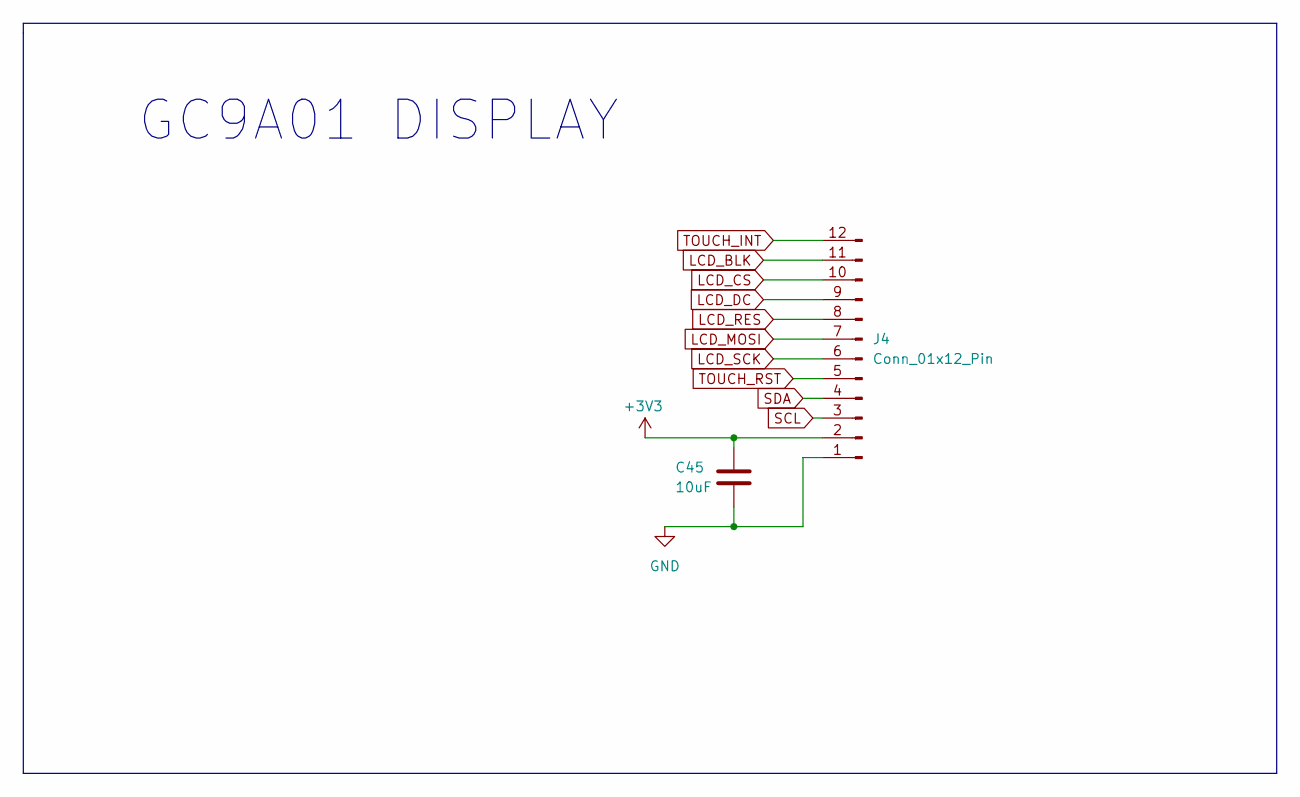
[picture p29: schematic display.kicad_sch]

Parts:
C45: 10uF; C_0402_1005Metric
J4: Conn_01x12_Pin; SolderPads_2mm_12

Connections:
+3V3: C45.1, J4.2; also elsewhere on the board
GND: C45.2, J4.1; also elsewhere on the board
LCD_BLK: J4.11; also elsewhere on the board
LCD_CS: J4.10; also elsewhere on the board
LCD_DC: J4.9; also elsewhere on the board
LCD_MOSI: J4.7; also elsewhere on the board
LCD_RES: J4.8; also elsewhere on the board
LCD_SCK: J4.6; also elsewhere on the board
SCL: J4.3; also elsewhere on the board
SDA: J4.4; also elsewhere on the board
TOUCH_INT: J4.12; also elsewhere on the board
TOUCH_RST: J4.5; also elsewhere on the board

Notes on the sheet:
GC9A01 DISPLAY

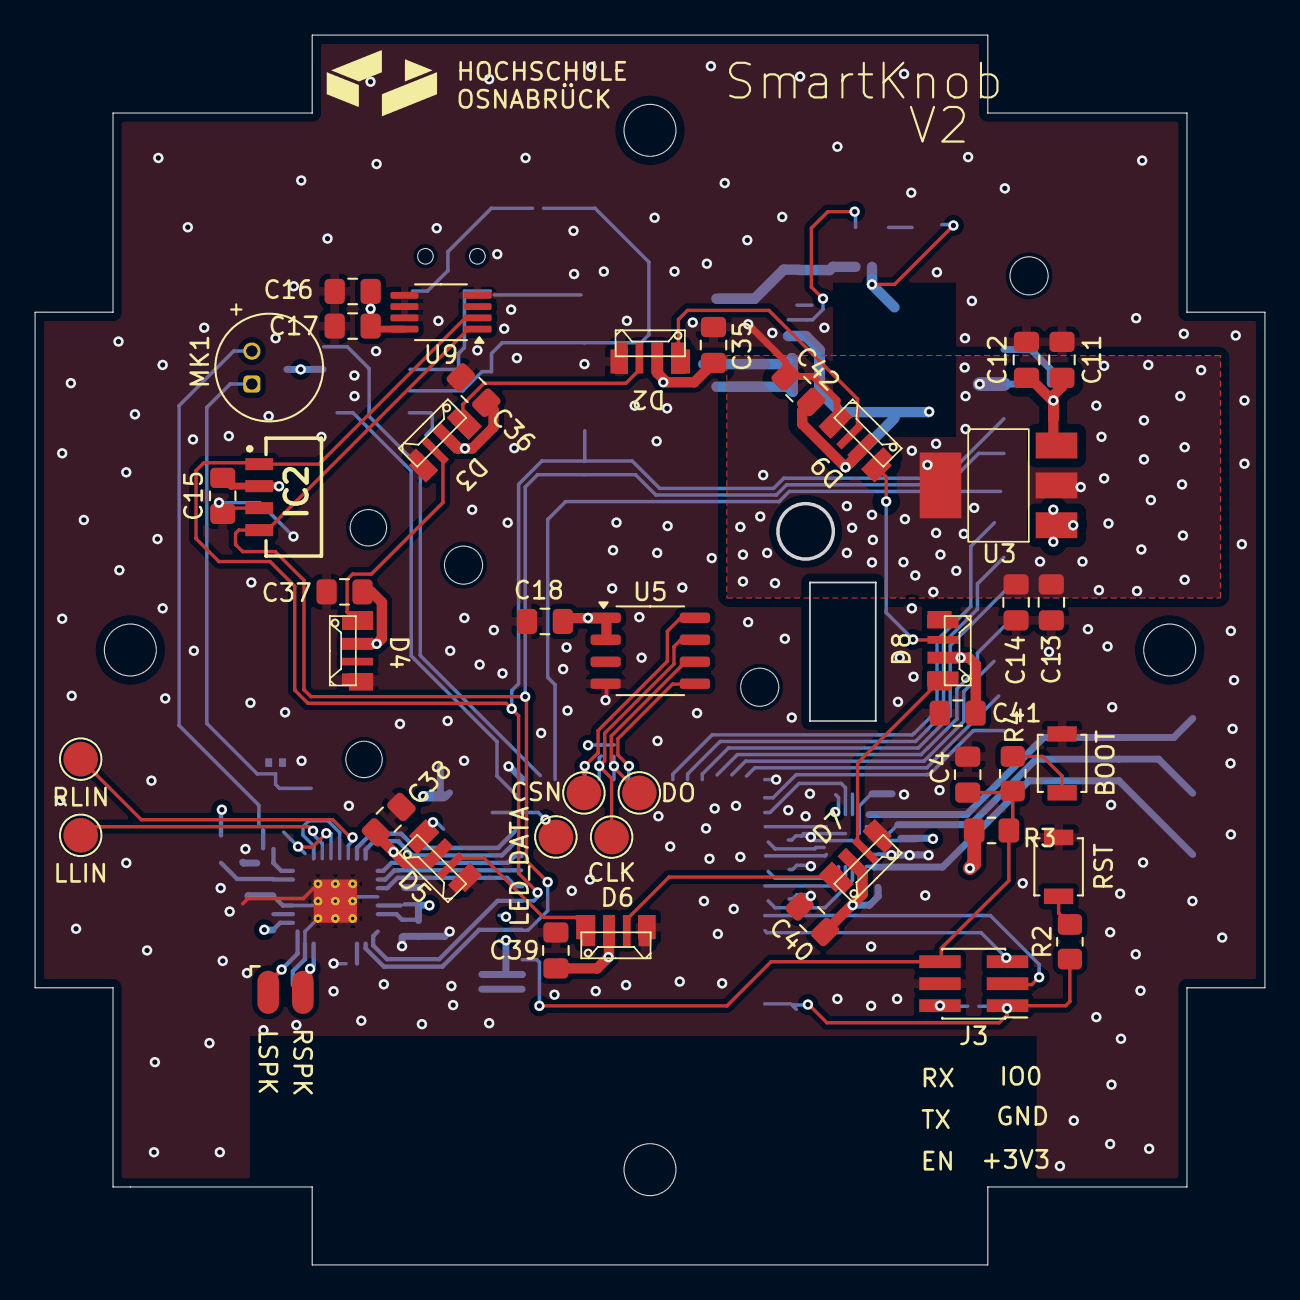
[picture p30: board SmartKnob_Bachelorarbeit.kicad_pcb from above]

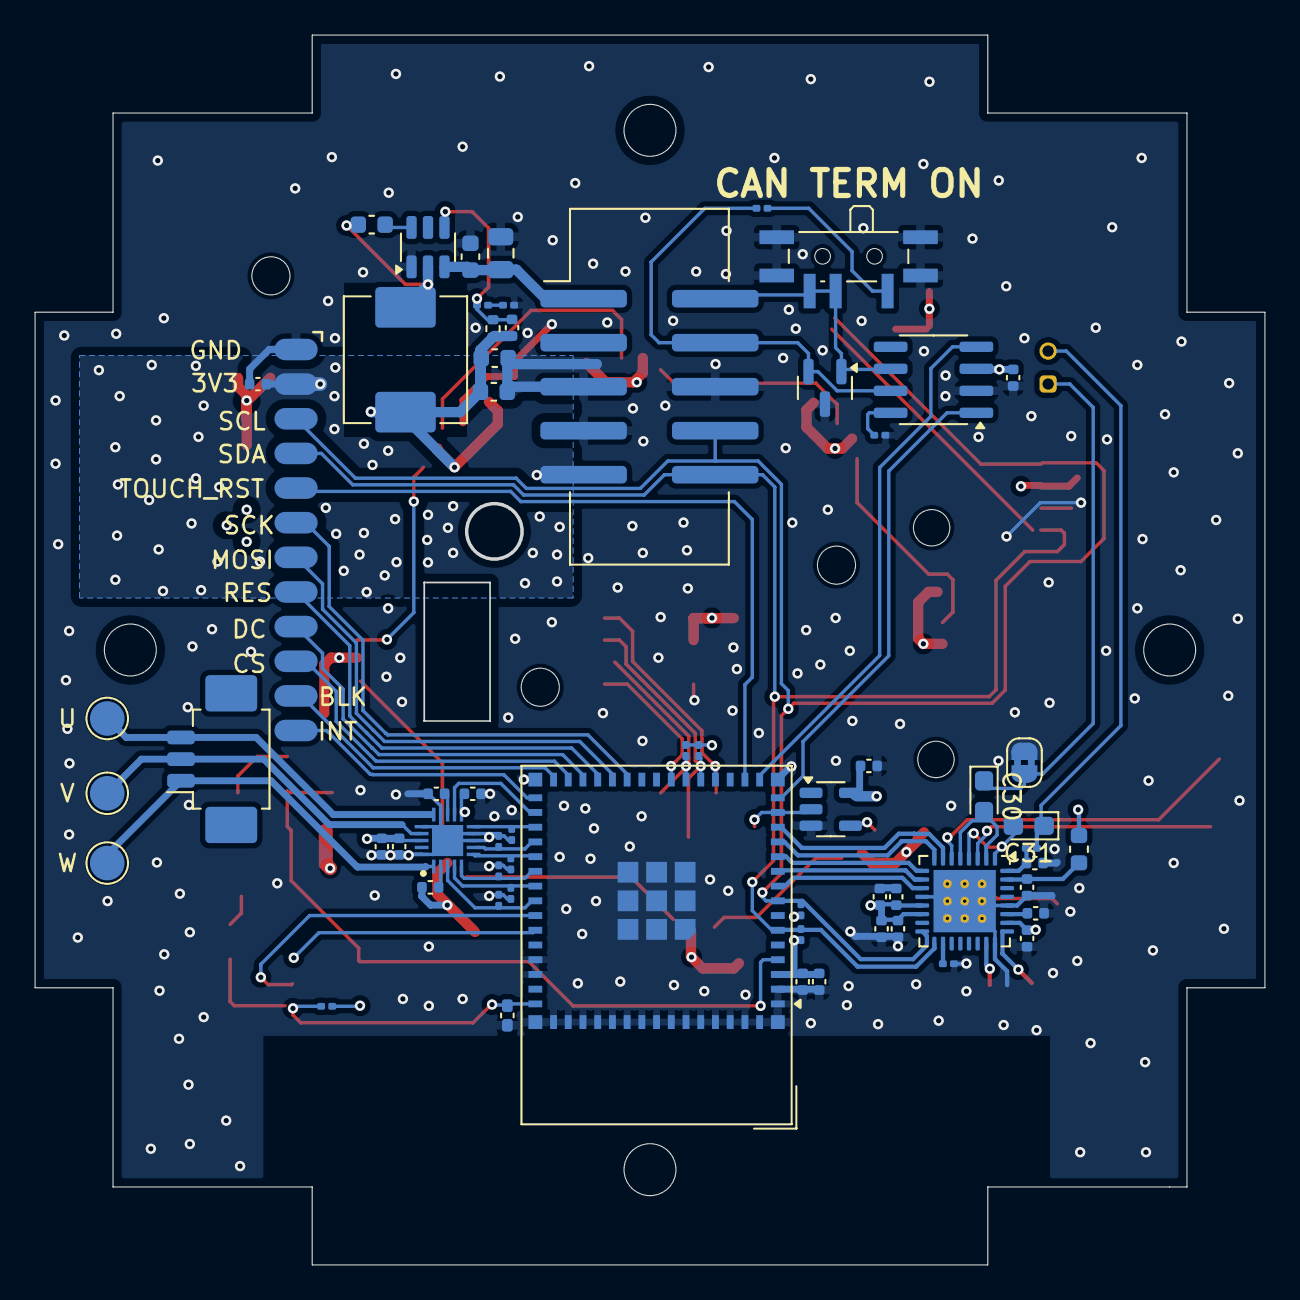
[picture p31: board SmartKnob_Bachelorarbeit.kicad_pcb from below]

Board: 4 copper layers, 71.0 x 71.0 mm, 110 parts (62 on the bottom side), 72 nets.

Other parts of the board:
H4#2: MountingHole; MountingHole_2.1mm

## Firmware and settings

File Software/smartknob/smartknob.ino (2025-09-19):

#include <HardwareSerial.h>
#include <LovyanGFX.hpp>

#include <CST816S.h>

#include <Adafruit_NeoPixel.h>
#include "Adafruit_MCP9808.h"
#include <SparkFun_VEML7700_Arduino_Library.h>
#include "MT6701.h"
#include <SimpleFOC.h>


//DISPLAY PINS
#define TFT_MOSI 26
#define TFT_SCLK 21
#define TFT_CS   34
#define TFT_DC   33
#define TFT_RST  47

//MOTOR PINS
#define TMC_UH 42
#define TMC_VH 41
#define TMC_WH 40
#define TMC_UL 39
#define TMC_VL 37
#define TMC_WL 38

// Temperature Sensor, Light Sensor, Touch Controller
#define SDA 2
#define SCL 4

#define TOUCH_RST 13
#define TOUCH_INT 35

//MAGNETIC ENCODER
#define SDA_ME 17
#define SCL_ME 16

//RGB LEDS
#define NUMPIXELS 8
#define LEDDATA 10


HardwareSerial mySerial(1);  // Use UART1 (UART0 is often used for USB-Serial)

// // Motor instance
BLDCMotor motor = BLDCMotor(4);  // Number of pole pairs

// Driver instance
BLDCDriver6PWM driver = BLDCDriver6PWM(TMC_UH,TMC_UL,TMC_VH,TMC_VL,TMC_WH,TMC_WL);  

//RGB leds instance 
Adafruit_NeoPixel pixels(NUMPIXELS, LEDDATA, NEO_GRB + NEO_KHZ800);

// Create the MCP9808 temperature sensor instance
Adafruit_MCP9808 tempsensor = Adafruit_MCP9808();

//Brightness sensor instance
VEML7700 lightsensor; 

//Magnetic Encoder instance
MT6701 encoder;

//touch controller instance
CST816S touch(SDA, SCL, TOUCH_RST, TOUCH_INT);	


// Display objects
lgfx::LGFX_Device tft;
lgfx::Panel_GC9A01 panel;
lgfx::Bus_SPI bus;
LGFX_Sprite sprite(&tft);


//Setup for Magnetic Encoder
float lastAngle = 0;
const float angleThreshold = 25.0;


//to measure last time in menu and avoid "ghost" touches 
unsigned long lastMenuExitTime = 0;  


// Menu setup
const int screenWidth = 240;
const int screenHeight = 240;
const int optionCount = 4;
const String menuOptions[optionCount] = { "Data", "Lights", "Motor", "Music" };

int selectedIndex = 0;
int targetIndex = 0;
float slideOffset = 0.0;
const float slideSpeed = 0.1;
const int optionSpacing = 120;  // More space between items

void setupDisplay() {
  // Configure SPI bus
  auto cfg = bus.config();
  cfg.spi_host = SPI2_HOST;
  cfg.spi_mode = 0;
  cfg.freq_write = 40000000;
  cfg.freq_read  = 16000000;
  cfg.spi_3wire  = true;
  cfg.use_lock   = true;
  cfg.dma_channel = SPI_DMA_CH_AUTO;
  cfg.pin_sclk = TFT_SCLK;
  cfg.pin_mosi = TFT_MOSI;
  cfg.pin_miso = -1;
  cfg.pin_dc   = TFT_DC;
  bus.config(cfg);

  panel.setBus(&bus);

  // Configure panel
  auto panel_cfg = panel.config();
  panel_cfg.pin_cs   = TFT_CS;
  panel_cfg.pin_rst  = TFT_RST;
  panel_cfg.pin_busy = -1;
  panel_cfg.memory_width  = 240;
  panel_cfg.memory_height = 240;
  panel_cfg.panel_width   = 240;
  panel_cfg.panel_height  = 240;
  panel_cfg.offset_x = 0;
  panel_cfg.offset_y = 0;
  panel_cfg.offset_rotation = 0;
  panel_cfg.dummy_read_pixel = 8;
  panel_cfg.dummy_read_bits  = 1;
  panel_cfg.readable = false;
  panel_cfg.invert    = true;
  panel_cfg.rgb_order = false;
  panel_cfg.dlen_16bit = false;
  panel_cfg.bus_shared = false;
  panel.config(panel_cfg);

  // Connect everything together
  tft.setPanel(&panel);
  tft.init();
  tft.setRotation(3); //270 degrees to the right
}

void drawArrow() {
  int centerX = screenWidth / 2;
  int tipY = screenHeight / 2 - 30;  // Text vertical center
  int arrowHeight = 12;
  int arrowWidth = 24;

  sprite.fillTriangle(
    centerX, tipY - 1,                           // Tip just above text center
    centerX - arrowWidth / 2, tipY - arrowHeight,
    centerX + arrowWidth / 2, tipY - arrowHeight,
    TFT_WHITE
  );
}

void drawMenu() {
  sprite.fillScreen(TFT_BLACK);
  int centerX = screenWidth / 2;

  for (int i = 0; i < optionCount; ++i) {
    int dx = (i - selectedIndex) * optionSpacing - slideOffset;
    int x = centerX + dx;
    int y = screenHeight / 2; //- 20;

    uint16_t color = (i == selectedIndex) ? TFT_WHITE : TFT_WHITE;
    sprite.setTextColor(color);
    sprite.setTextDatum(MC_DATUM);
    sprite.drawString(menuOptions[i], x, y, 2);
  }

  drawArrow();
  sprite.pushSprite(0, 0);
}

void updateSlide() {
  float diff = (targetIndex - selectedIndex) * optionSpacing - slideOffset;
  if (abs(diff) < 1.0) {
    selectedIndex = targetIndex;
    slideOffset = 0.0;
  } else {
    slideOffset += diff * slideSpeed;
  }
}

void showDataScreen(int screenID) {
  // 🛑 Wait for the SELECT button to be released
  motor.enable();//activate motor
  while (touch.available());

  const int screenWidth = tft.width();
  const int screenHeight = tft.height();

  // Create sprite (same size as screen)
  sprite.createSprite(screenWidth, screenHeight);
  sprite.setTextColor(TFT_WHITE, TFT_BLACK);
  sprite.setTextSize(2);

  //wake up tempsensor
  tempsensor.wake();   // wake up, ready to read!

  while (true) {
    sprite.fillScreen(TFT_BLACK);  // Clear sprite every frame

    switch (screenID) {
      case 0: {
        String first_title = "Temperature:";
        int first_titleWidth = sprite.textWidth(first_title);
        sprite.setCursor((screenWidth - first_titleWidth) / 2, 70);
        sprite.println(first_title);

        float c = tempsensor.readTempC();
        String temp_value = String(c);//"24.5 C";
        int temp_valueWidth = sprite.textWidth(temp_value);
        sprite.setCursor((screenWidth - temp_valueWidth) / 2, 110);
        sprite.println(temp_value);

        String second_title = "Lux:";
        int second_titleWidth = sprite.textWidth(second_title);
        sprite.setCursor((screenWidth - second_titleWidth) / 2, 150);
        sprite.println(second_title);

        float f = lightsensor.getLux();
        String flux_value = String(f);
        int flux_valueWidth = sprite.textWidth(flux_value);
        sprite.setCursor((screenWidth - flux_valueWidth) / 2, 180);
        sprite.println(flux_value);


        break;
      }
      case 1: {
        String title = "Lights:";
        int titleWidth = sprite.textWidth(title);
        sprite.setCursor((screenWidth - titleWidth) / 2, 60);
        sprite.println(title);


        //RGB LEDS visual effect
        for (int i = 0; i < NUMPIXELS; i++) {
          pixels.clear();  // Turn off all LEDs
          pixels.setPixelColor(i, pixels.Color(0, 0, 255));  // Set current LED to blue
          pixels.show();
          delay(100);
        }

        // String value = "24:05";
        // int valueWidth = sprite.textWidth(value);
        // sprite.setCursor((screenWidth - valueWidth) / 2, 110);
        // sprite.println(value);
        break;
      }
      case 2: {
        String title = "Motor:";
        int titleWidth = sprite.textWidth(title);
        sprite.setCursor((screenWidth - titleWidth) / 2, 60);
        sprite.println(title);

        String value = "All okay";
        int valueWidth = sprite.textWidth(value);
        sprite.setCursor((screenWidth - valueWidth) / 2, 110);
        sprite.println(value);

        motor.loopFOC();
        motor.move(2);  // rad/s

        break;
      }
      case 3: {
        String title = "Music:";
        int titleWidth = sprite.textWidth(title);
        sprite.setCursor((screenWidth - titleWidth) / 2, 60);
        sprite.println(title);

        String value = "Coming soon";
        int valueWidth = sprite.textWidth(value);
        sprite.setCursor((screenWidth - valueWidth) / 2, 110);
        sprite.println(value);

        //Audioamplifier code
        

        break;
      }
    }

    sprite.pushSprite(0, 0);  // Push entire sprite to screen

    
    delay(10);
 
    //Exit Menu
    if(touch.available()){
      while(touch.available());
      mySerial.println("Exiting option!");
      
      //deactivate motor's torque
      motor.move(0);     // Stop motor
      motor.disable();   // Disable driver to remove resistance
      lastAngle = encoder.angleRead();  // Synchronize last read angle

      //turn off all leds
      pixels.clear();  // Turn off all LEDs
      pixels.show();

      //reset the touch controller 
      digitalWrite(TOUCH_RST, LOW);
      delay(5);
      digitalWrite(TOUCH_RST, HIGH);  
      delay(50);

      tempsensor.shutdown_wake(1); // shutdown MSP9808 - power consumption ~0.1 mikro Ampere
      sprite.deleteSprite();  // Clean up sprite memory
      
      lastMenuExitTime = millis();
      delay(300);//wait for motor to really stop moving
      break;
    }
  }
  //Tempsensor sleep
  tempsensor.shutdown_wake(1); // shutdown MSP9808 - power consumption ~0.1 mikro Ampere

  sprite.deleteSprite();  // Clean up sprite memory
}



void setup() {
  //Initialize Serial Output
  mySerial.begin(115200, SERIAL_8N1, 44, 43);  // RX, TX

  //Initialize Magnetic Encoder  
  Wire.setPins(SDA_ME,SCL_ME);
  Wire.begin();
  encoder.initializeI2C();

  //Initialize Temperature and Light Sensors
  Wire1.begin(SDA,SCL);
  tempsensor.begin(0x18, &Wire1);
  tempsensor.setResolution(3);

  lightsensor.begin(Wire1);

  //Initialize RGB Leds
  pixels.begin();

  //Initialize Touch Controller
  pinMode(TOUCH_RST, OUTPUT);//first reset the controller
  digitalWrite(TOUCH_RST, LOW);
  delay(5);
  digitalWrite(TOUCH_RST, HIGH);  
  delay(50);

  touch.begin();

  //Initialize Gimbal Motor
  driver.voltage_power_supply = 12;  // Set according to your power supply (e.g., 6V)
  // limit the maximal dc voltage the driver can set
  // as a protection measure for the low-resistance motors
  // this value is fixed on startup
  driver.voltage_limit = 6;
  driver.init();

  motor.linkDriver(&driver);
  motor.controller = MotionControlType::velocity_openloop;
  motor.init();

  //Initialize Display
  setupDisplay();

  sprite.setColorDepth(8);
  sprite.createSprite(screenWidth, screenHeight);

  sprite.setFont(&fonts::Font2);
  sprite.setTextSize(2);

}



void loop() {

  updateSlide();
  drawMenu();

   if (touch.available() && millis() - lastMenuExitTime > 1000) { //avoid debounces and automatic entering in menu if last time in menu <1000s
    delay(400);
    mySerial.println("Entering option!");
    showDataScreen(targetIndex);
    delay(200);

    //recreate menu after exiting the options
    sprite.createSprite(screenWidth, screenHeight);
    sprite.setFont(&fonts::Font2);
    sprite.setTextSize(2);

  }


  float angle = encoder.angleRead();

  float delta = angle - lastAngle;

  // Handle wrap-around at 0°/360°
  if (delta > 180.0) delta -= 360.0;
  if (delta < -180.0) delta += 360.0;

  if (abs(delta) >= angleThreshold) {
    // Rotation detected
    if (delta > 0) {
      mySerial.println("Rotated counter-clockwise 25°");
      targetIndex = (targetIndex > 0) ? targetIndex - 1 : 3;
      
    } else {
      mySerial.println("Rotated clockwise 25°");
      targetIndex = (targetIndex < optionCount -1 ) ? targetIndex + 1 : 0;
    }

    lastAngle = angle;  // Update reference point
  }

  delay(16);

  

}

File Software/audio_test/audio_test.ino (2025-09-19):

extern "C" {
#include "driver/i2c_master.h"
}

#include "FreeRTOS.h"
#include "task.h"
#include <nau88c22.hh>
#include <AudioPlayer.hh>
#include "fanfare.h"
#include <HardwareSerial.h>
//#include <Wire.h> issues when including Wire.h conflicts with i2c_new_master_bus


#define AUDIO 1


HardwareSerial mySerial(1); 

//PINS
constexpr gpio_num_t PIN_I2C_SDA = (gpio_num_t)2;
constexpr gpio_num_t PIN_I2C_SCL = (gpio_num_t)4;

constexpr gpio_num_t PIN_I2S_MCLK = (gpio_num_t)5;
constexpr gpio_num_t PIN_I2S_FS = (gpio_num_t)9;
constexpr gpio_num_t PIN_I2S_DAC = (gpio_num_t)6;
constexpr gpio_num_t PIN_I2S_ADC = (gpio_num_t)7;
constexpr gpio_num_t PIN_I2S_BCLK = (gpio_num_t)8;


// Global variables
AudioPlayer::Player *mp3player{nullptr};
i2c_master_bus_handle_t i2c_master_handle{nullptr};




void audioTask(void *pvParameters){
  
  while(1){
    mp3player->Loop();
    }

  
 }

    void AudioLoop(void *pvParameters){
        TickType_t lastWakeTime;
        const TickType_t FREQUENCY = pdMS_TO_TICKS(20);
        while(mp3player){
            xTaskDelayUntil( &lastWakeTime, FREQUENCY);
            mp3player->Loop();
        }
    }

void setup() {

mySerial.begin(115200, SERIAL_8N1, 44, 43);


   
    // I2C configuration
    i2c_master_bus_config_t i2c_mst_config = {
        .i2c_port = I2C_NUM_0,
        .sda_io_num = PIN_I2C_SDA,
        .scl_io_num = PIN_I2C_SCL,
        .clk_source = I2C_CLK_SRC_DEFAULT,
        .glitch_ignore_cnt = 7,
        .intr_priority=0,
        .trans_queue_depth=0,
        .flags={
            .enable_internal_pullup=1,
        }
    };

    // Initialize I2C
    esp_err_t err = i2c_new_master_bus(&i2c_mst_config, &i2c_master_handle);
    if (err != ESP_OK) {
        // Handle error
    }

    //Initialize codec and player
    nau88c22::M *codec = new nau88c22::M(i2c_master_handle, PIN_I2S_MCLK, PIN_I2S_BCLK, PIN_I2S_FS, PIN_I2S_DAC);
    mp3player = new AudioPlayer::Player(codec);
    mp3player->Init();

    mp3player->PlayMP3(&fanfare_mp3[0], fanfare_mp3_len, 255, true);

    //Task??
    xTaskCreate(audioTask,"AudioTask",8192*4,NULL,1,NULL);
    
}

void loop() {
  #if 0
  
    if(mp3player){
        mp3player->Loop();
       
      }
   #endif

      
 }
